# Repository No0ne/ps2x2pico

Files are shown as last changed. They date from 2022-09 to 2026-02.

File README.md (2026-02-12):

# ps2x2pico
USB keyboard/mouse to PS/2 interface converter using a Raspberry Pi Pico

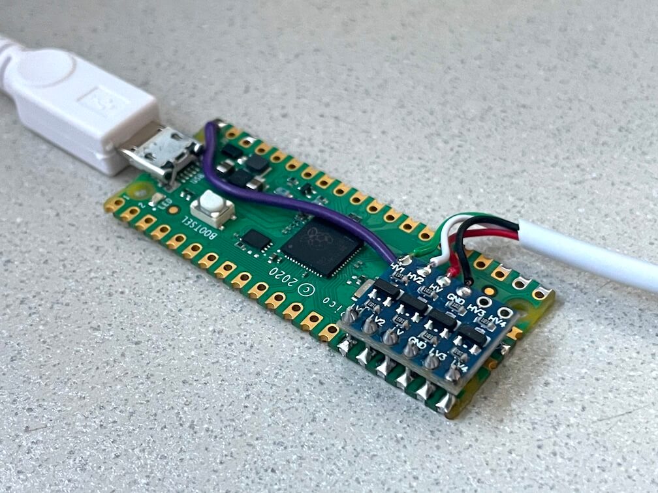
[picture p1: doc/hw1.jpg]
hw1
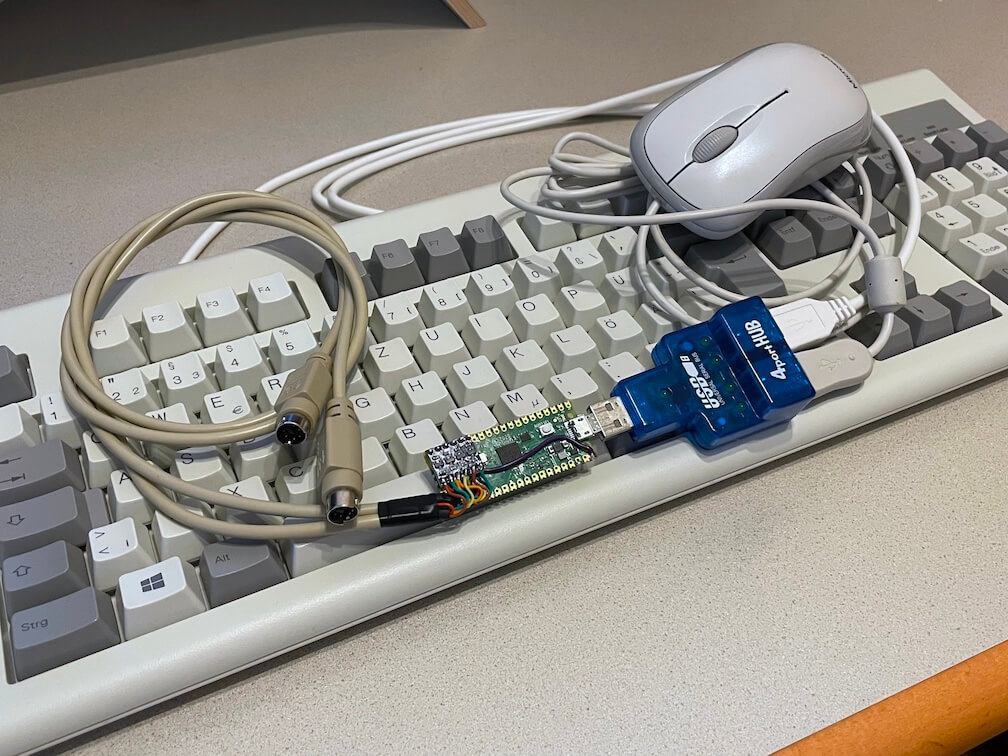
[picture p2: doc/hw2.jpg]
hw2
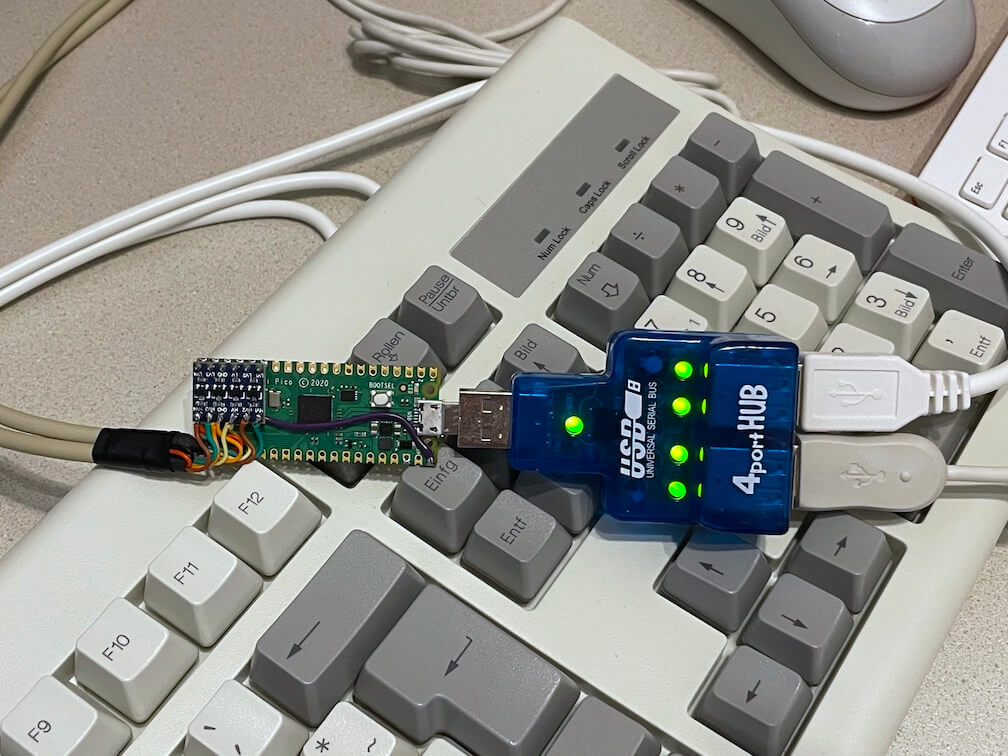
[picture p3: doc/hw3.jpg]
hw3
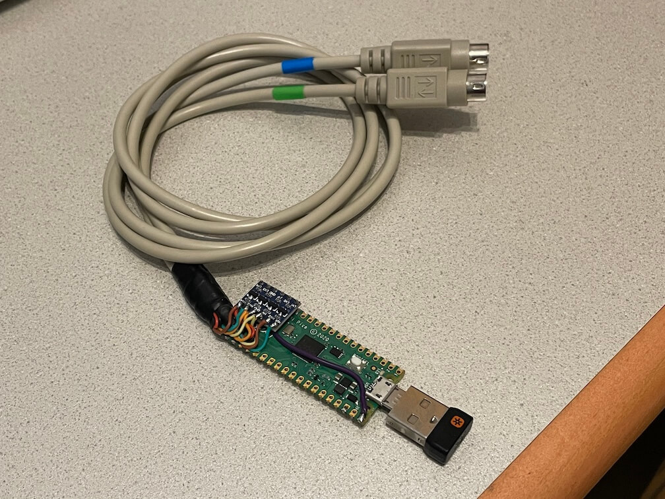
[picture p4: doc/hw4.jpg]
hw4
| | | | |
|-|-|-|-|

Keyboard only (incl. PC-XT) variant: https://github.com/No0ne/ps2pico  
There is also an alternative ps2pico firmware for the PC-XT and ps2x2pico hardware: [ps2pico-XT-alt.uf2](https://github.com/No0ne/ps2pico/releases/tag/2.2)

Additional excellent documentation by Ray: https://minuszerodegrees.net/keyboard/ps2x2pico.htm

[PicoMiteVGA](https://geoffg.net/picomitevga.html) variant: https://github.com/No0ne/hid2cdc

[PiKVM](https://pikvm.org) integration:
* https://docs.pikvm.org/pico_hid/
* https://docs.pikvm.org/pico_hid_bridge/

[ITX-Llama](https://www.vogons.org/viewtopic.php?t=93480) integration:
https://github.com/eivindbohler/itxllama

# Usage
* Download `ps2x2pico.uf2` from https://github.com/No0ne/ps2x2pico/releases
* Copy `ps2x2pico.uf2` to your Pi Pico by pressing BOOTSEL before pluggging in.
* 3.3V/5V conversion is done using a bi-directional level shifter: https://learn.sparkfun.com/tutorials/bi-directional-logic-level-converter-hookup-guide/
* Afterwards connect a USB keyboard and/or mouse using an OTG-adapter and optional USB hub.
* Also works with wireless keyboards and mice with a dedicated USB receiver.

⚠️ Please note that some older motherboards have non-resettable fuses rated
under 300mA.

**Check the power consumption of your keyboard/mouse/hub first before plugging
in!**

Level Shifter wiring diagram

PS/2 Pinout diagram

⚠️ Do not assume wire colors will match cables depicted in photos. Double-check
your pinout with a multimeter.

# PS/2 passthru
If you also want to use a real PS/2 keyboard and mouse together with your USB devices you can mount another level shifter on top of the pico. These two ports work as PS/2 inputs and are passed through to the PS/2 output ports.
* GPIO3 LV1 - keyboard data
* GPIO4 LV2 - keyboard clock
* GPIO5 LV - 3.3V pull-up
* GND - GND
* GPIO6 LV3 - mouse data
* GPIO7 LV4 - mouse clock

Don't forget to wire HV to 5V and your PS/2 sockets to power the connected PS/2 devices.

PS/2 passthru is especially useful with the PiKVM [Pico HID](https://docs.pikvm.org/pico_hid/) or [Pico HID Bridge](https://docs.pikvm.org/pico_hid_bridge/) as you can continue using your existing peripherals.  
⚠️ Please note that the [UF2 from PiKVM](https://github.com/pikvm/kvmd/releases) uses different GPIOs due to jumper pins:
* GPIO26 LV1 - keyboard data
* GPIO27 LV2 - keyboard clock
* GPIO16 LV3 - mouse data
* GPIO17 LV4 - mouse clock

Don't forget to wire LV to 3.3V and GND to GND separately as the level shifter does not fit directly on top of the pico. 

# Troubleshooting
You can hook up a USB serial adapter to **GPIO0** for additional debugging output. The serial settings are **115200** baud, **8** data bits and **no parity**. You can also use another Pico running the [pico-uart-bridge](https://github.com/Noltari/pico-uart-bridge) for this.

⚠️ If you have a **YD-RP2040** (see silkscreen on back of board if unsure) and
are not using a USB hub with its own power supply, you need to bridge two pads
of the diode pair near the USB-C port as seen here:

Fix for YD-RP2040

# Build

Install needed libraries and tools:

```sh
sudo apt install cmake gcc-arm-none-eabi build-essential pkg-config libusb-1.0-0-dev libusb-1.0-0
```

Get the Raspberry Pi Pico SDK version 1.5.1:

```sh
git clone https://github.com/raspberrypi/pico-sdk
export PICO_SDK_PATH=/path/to/pico-sdk
cd $PICO_SDK_PATH
git checkout 1.5.1
git submodule update --init
```

Update to the latest TinyUSB release 0.17.0:
```sh
cd $PICO_SDK_PATH/lib/tinyusb
git checkout 0.17.0
```

Generate the UF2 file:
```sh
cd /path/to/ps2x2pico
mkdir build
cd build
cmake ..
make
```

# Case

There are two case versions for this project, one for the hat variant in `freecad/` and one for the level shifter version in `openscad/`.

## Level shifter version

The case is snap fit and doesn't require any fasteners. You can print it as is using `ps2x2pico_case.stl` in your slicer but various customisation options are included in the underlying OpenSCAD model `ps2x2pico_case.scad` should you need them. This allows you to adjust tolerances or clearances of the height of the case and the various holes and support posts.

Note that when opening the case in OpenSCAD the [BOSL2](https://github.com/BelfrySCAD/BOSL2) library is required.

# Resources
* https://github.com/No0ne/ps2pico
* https://wiki.osdev.org/PS/2_Keyboard
* https://wiki.osdev.org/PS/2_Mouse
* https://wiki.osdev.org/Mouse_Input
* https://wiki.osdev.org/%228042%22_PS/2_Controller
* http://www-ug.eecg.toronto.edu/msl/nios_devices/datasheets/PS2%20Keyboard%20Protocol.htm
* http://www-ug.eecg.utoronto.ca/desl/nios_devices_SoC/datasheets/PS2%20Mouse%20Protocol.htm
* Archive.org links for the dead links in the pages above
  * [Main page PS/2 Keyboard Protocol](https://web.archive.org/web/20160414014033if_/http://www.computer-engineering.org/ps2keyboard/)
    * [Scan code set 1](https://web.archive.org/web/20160410193756if_/http://www.computer-engineering.org/ps2keyboard/scancodes1.html)
    * [Scan code set 2](https://web.archive.org/web/20160414030011if_/http://www.computer-engineering.org/ps2keyboard/scancodes2.html)
    * [Scan code set 3](https://web.archive.org/web/20160410184920if_/http://www.computer-engineering.org/ps2keyboard/scancodes3.html)
  * [Main page PS/2 Mouse Protocol](https://web.archive.org/web/20160414013310if_/http://www.computer-engineering.org/ps2mouse/)

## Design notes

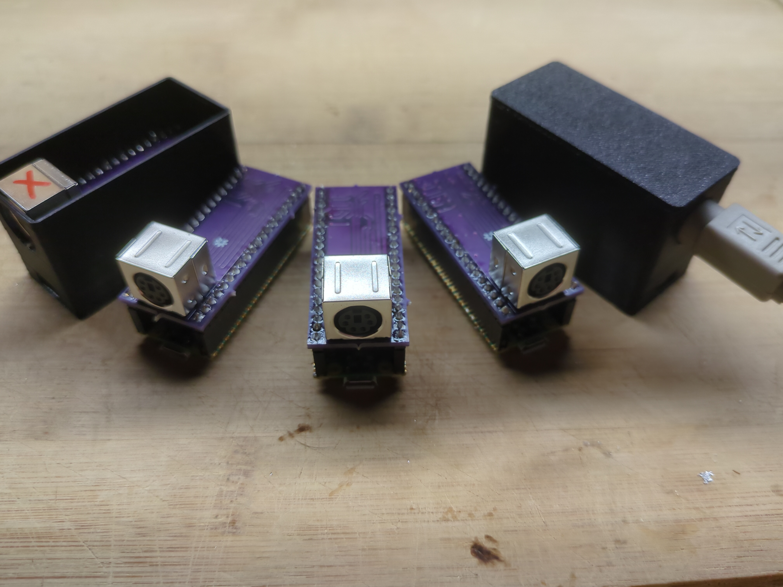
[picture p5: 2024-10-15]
doc/completed.jpg

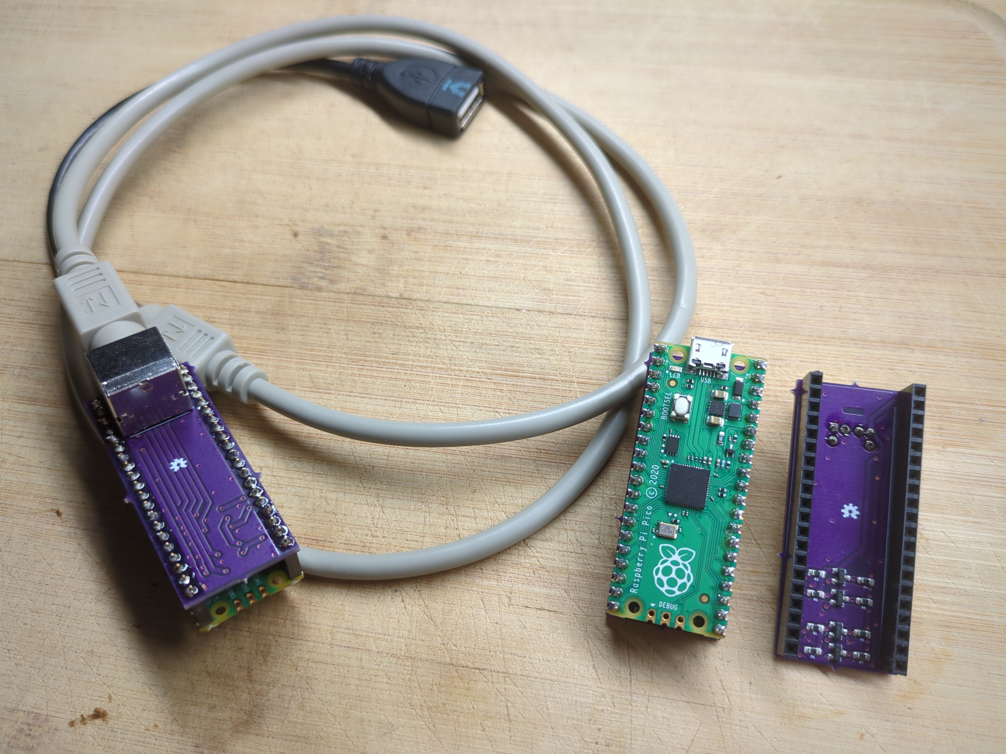
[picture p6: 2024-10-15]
doc/usb-to-ps2-prototypes.jpg

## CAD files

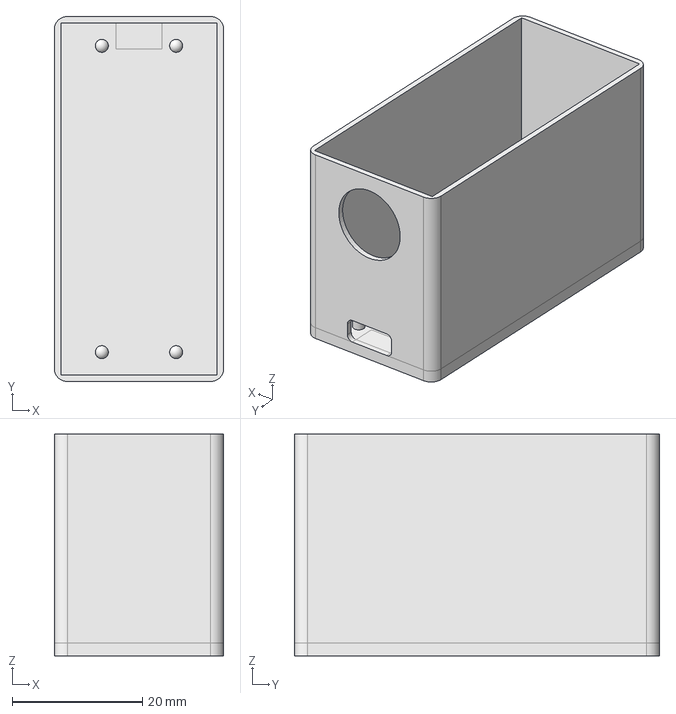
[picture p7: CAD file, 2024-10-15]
freecad/case.FCStd
26.0 x 56.0 x 34.0 mm

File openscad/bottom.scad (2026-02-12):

include <BOSL2/std.scad>
include <chamfered_section.scad>
include <usb_socket.scad>
include <cable_holes.scad>
include <pi_pico.scad>
include <rings.scad>
include <support_posts.scad>

module bottom(inner_ring_dimensions, rounding, wall_thickness, socket_cube, cable_holes_cube, usb_socket, front_scale_factor, ring_height, cable_diameter, hole_spacing, 
    chamfer_bottom_dimensions, chamfer_height, chamfer_top_dimensions, void_top, void_bottom, base_height, shift_distance, post_intervals, support_diameter, support_height, 
    retention_height, retention_diameter, total_post_height, posts_bounding_box, pico_height, support_adjustment, anchor = CENTER, spin = 0, orient = UP) {

  attachable(anchor, spin, orient, size=point3d(chamfer_bottom_dimensions, chamfer_height), size2=chamfer_top_dimensions) {
    // Chamfered section
    chamfered_section(chamfer_top_dimensions, chamfer_bottom_dimensions, wall_thickness, void_top, void_bottom, chamfer_height, base_height, rounding) {
      align(TOP) inner_ring(inner_ring_dimensions, rounding, wall_thickness, socket_cube, cable_holes_cube); // Inner ring
      align(TOP, FRONT) usb_socket(usb_socket, socket_cube, front_scale_factor, wall_thickness, ring_height, false); // Usb socket, bottom half
      align(TOP, BACK) cable_holes(cable_holes_cube, cable_diameter, hole_spacing); // Cable holes

      // Support posts
      align(BOTTOM, inside=true) {
        up(base_height) {
          fwd(shift_distance) support_posts(post_intervals, support_diameter, support_height, retention_height, total_post_height, posts_bounding_box, retention_diameter,
              support_adjustment, true) {
            // Pi Pico
            align(TOP) {
              hide_this() down(pico_height) pi_pico(pico_height);
            }
          }
        }
      }
    }

    children();
  }
}

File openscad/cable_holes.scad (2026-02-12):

include <BOSL2/std.scad>

module cable_holes(cable_holes_cube, cable_diameter, hole_spacing, anchor = CENTER, spin = 0, orient = UP) {
  module holes() {
    diff() {
      cube(cable_holes_cube, center=true);
      tag("remove") left((cable_diameter / 2) + (hole_spacing / 2)) cyl(h=cable_holes_cube.y + 0.02, d=cable_diameter, orient=BACK);
      tag("remove") right((cable_diameter / 2) + (hole_spacing / 2)) cyl(h=cable_holes_cube.y + 0.02, d=cable_diameter, orient=BACK);
    }
  }

  attachable(anchor, spin, orient, size=[cable_holes_cube.x, cable_holes_cube.y, cable_holes_cube.z / 2]) {
    up(cable_holes_cube.z / 4) bottom_half() holes();

    children();
  }
}

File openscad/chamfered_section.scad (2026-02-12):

include <BOSL2/std.scad>

module chamfered_section(chamfer_top_dimensions, bottom_dimensions, wall_thickness, void_top, void_bottom, chamfer_height, base_height, rounding, pinhole_diameter, pinhole=false,
    anchor = CENTER, spin = 0, orient = UP) {
  attachable(anchor, spin, orient, size=point3d(bottom_dimensions, chamfer_height), size2=chamfer_top_dimensions) {
    diff() {
      prismoid(size1=bottom_dimensions, size2=chamfer_top_dimensions, h=chamfer_height, rounding=rounding, center=true)
        // Inner void
        align(BOTTOM, inside=true) {
          up(base_height) {
            prismoid(size1=void_bottom, size2=void_top, h=chamfer_height - base_height + 0.01, rounding=rounding, center=true) {
              // BOOTSEL pinhole
              if(pinhole) {
                align(BOTTOM + FRONT) {
                  up(0.01) back(12.25 + (0.5 * pinhole_diameter)) left(3.75) cyl(h=base_height + 0.02, d=pinhole_diameter); 
                }
              }
            }
          }
        }
    }

    children();
  }
}

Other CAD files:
openscad/pi_pico.scad
openscad/ps2x2pico_case.scad
openscad/rings.scad
openscad/support_posts.scad
openscad/top.scad
openscad/usb_socket.scad

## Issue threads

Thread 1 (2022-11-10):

Mouse Issues

serisman, 2022-11-10:
First of all, awesome project!

It was super easy to get a Logitech wireless keyboard/mouse (K345/M275) combo up and running on an old DOS PC with only PS2 ports.

I haven't found any issues with the keyboard at all, but the mouse code seems buggy.

I am testing with both the CTMOUSE.EXE driver as well as Microsoft MOUSE.EXE driver.  With both drivers, by default, the mouse cursor jumps around pretty randomly and it seems like button presses are being toggled without actually pressing anything.  No amount of tweaking the driver's resolution seems to help things.  Eventually, I found that the /O switch on CTMOUSE (which enables wheel support) seems to work... about half the time.  Other times it just reports 'Error: device not found".

I think what is happening is that this code is always reporting 'Mouse with scroll wheel' and sending 4-byte 'Intellimouse' data packets, even when the computer hasn't asked for them (yet).  If I'm reading the documentation at [(https://wiki.osdev.org/PS/2_Mouse)](https://wiki.osdev.org/PS/2_Mouse) correctly, it seems like by default the mouse is supposed to report back type 0 'Standard PS/2 mouse' and send 3-byte data packets until a specific initialization sequence is requested to put the mouse into enhanced mode at which point it will report back type 3 'Mouse with scroll wheel' and send 4-byte data packets.

serisman, 2022-11-10:
I did some further testing, and my assumption was indeed true.  I made some code changes and now it works much better.  I'll clean it up and submit a pull request sometime tomorrow for you to review.

No0ne, 2022-11-10:
Hi, thanks for your feedback!
Yes you are right, the mouse support is still very sparse.

I've currently only tested it on Windows 2000 as there are still some issues left. I need to port the PS/2 protocol part to the Pico PIOs so that both channels can send/receive independently. At the moment it is just a port from [/No0ne/ps2pico] where CPU based bitbanging was enough since theres only the keyboard ps/2 channel. In my other repo [/No0ne/ps2x2pico-rs] I already tried PIO support with Rust, but there USB support is more of a problem.

I also found out that all my USB mice with the PixArt chip still do native PS/2 using the green passive adapter!
E.g. the official Raspberry Pi Mouse or the Microsoft Basic Optical Mouse

I hope I'll finish the PIO implementation this year.

serisman, 2022-11-11:
I'm using this with a Logitech wireless keyboard/mouse receiver, so those green passive adapters won't work for me.  :(  That's why I was excited to find your project to begin with.

I just submitted Pull Request #2 with some better mouse code for you to review.  It still isn't a 100% complete mouse driver, but does the main stuff better than before (i.e. switching between the different mouse types and honoring the corresponding data packet format).

I have tested this in MS DOS with the CTMOUSE.EXE and MS MOUSE.EXE drivers as well as with Windows 3.11, and all seems well.  I did run into a weird race condition when trying to run `ctmouse /o` where the 'key up' event of the ENTER key from running the command takes time away from the mouse initialization and causes weird issues.  If I just use `ctmouse` or put the command in a batch file with a pre-delay, everything works correctly.  I suppose what you mention about using PIO is probably the real solution that is needed.

No0ne, 2022-11-11:
Thanks for your PR!
Quick sidenote: I did compile the UF2s with Pico-SDK develop branch because of this https://github.com/raspberrypi/pico-sdk/issues/483
Will do a new release with your enhancements soon!

serisman, 2022-11-11:
Yeah, I had to do something similar.  I think I just updated the tinyusb git submodule to the latest.  Without doing that, only the keyboard was working.  Took a while to track that one down.  Finally realized I could get some debugging info by connecting a USB TTL serial to the UART!

serisman, 2022-12-05:
That looks pretty promising!  I'll have to check it out in more detail later.

I had one other thought for optimization, although I'm not sure how useful it would be once the PIO work is done.  Anyway, might be helpful to have all the serial logging controlled by a debug flag and produce two different binaries (one for run-time, one for debug).  The serial output is very useful for debugging, but it does steal some time from the PS/2 code.  During normal operation it seems kinda wasteful for all that serial processing to continue to happen.  It's like shouting into the void with no one listening.

No0ne, 2022-12-07:
Please try the new binary from the pio-testing branch: https://github.com/No0ne/ps2x2pico/raw/pio-testing/ps2x2pico.uf2
I've only tested it on Windows 2000 so far, but there still seams to be an issue if you drag the typematic sliders in the keyboard preference panel. The mouse starts jumping vertically. Also the PIO code is still messy right now.

serisman, 2022-12-16:
@No0ne - I finally had a chance to do some testing of your pio-testing branch, and everything seems to be working fine on my side.  I did some testing with both MS-DOS 6.22 as well as Windows 3.11 and didn't notice any issues.  Good job!

No0ne, 2022-12-17:
Cool! I still have issues on Windows 2000, especially when changing key repeat settings in the system control panel. I think I need to capture some data between real PS/2 devices and different PCs and mimic the timings as close as possible.

No0ne, 2022-12-18:
The PIO code is much more refined right now, but still not working 100% of the time.
Please try if this is still happening with the latest build [5f96329]:
> I did run into a weird race condition when trying to run `ctmouse /o` where the 'key up' event of the ENTER key from running the command takes time away from the mouse initialization and causes weird issues.

Thanks!

serisman, 2022-12-23:
> The PIO code is much more refined right now, but still not working 100% of the time. Please try if this is still happening with the latest build [[5f96329](https://github.com/No0ne/ps2x2pico/commit/5f96329b8873e4b1af6377f1dd1dfc8af90bc5fa)]:
>
> > I did run into a weird race condition when trying to run `ctmouse /o` where the 'key up' event of the ENTER key from running the command takes time away from the mouse initialization and causes weird issues.

Sorry, but with the current version the mouse isn't working at all.  It works again if I rollback to the Dec 7th version as long as I have ctmouse in the autoexec.bat, but not if I just type it on the command line.

nanoant, 2023-08-20:
@No0ne @serisman Can you guys share Dec 7th version? (the link above is broken) The latest beta 0.6 does not work at all on my Toshiba 430CDT using my build described at #16. I see lot of communications in oscilloscope, but in the end laptop is not taking any external mouse events.

No0ne, 2023-08-20:
I'm currently rewriting the whole PIO code as part of integrating to the PiKVM pico hid project. I hope this will fix all mouse related issues, please give me some to finish.

No0ne, 2023-08-27:
@serisman if you still have the board around you could test the new pre-release: https://github.com/No0ne/ps2x2pico/releases/download/beta-0.7/ps2x2pico.uf2
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
nvllsvm, 2024-03-16:
V1.0 alpha works well with my G305 @ 500hz, though I needed to use PS2Rate to change the rate in Windows 98. The default was very choppy compared to using the same mouse with the [Minicom PS2 to USB adapter](https://www.amazon.com/gp/product/B00404YD8W/ref=ppx_yo_dt_b_search_asin_title?ie=UTF8&psc=1).

There also might be some small latency issues, though I'll need to test more.

No0ne, 2024-03-18:
Just checked and yes, Win98 default sets the rate to 0x28 = 40hz which means 25ms between transmits. I currently apply the sample rate requested by the host but if you want we could also hardcode it. Please explain if you have more details about stuttering, thanks!

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

seritools, 2024-03-24:
Just tested again with 1.0, works flawlessly over here. 🎉

And wow, PS2Rate makes a huge difference, TIL Win9x sets it to such a low value. Maybe having a second FW version or a HW switch through another GPIO for forcing a sample rate might make sense?

nvllsvm, 2024-03-24:
I've been testing a modification which forces a constant sample rate without any issues.
https://github.com/nvllsvm/ps2x2pico/commit/f867858986a37cafbccab6e7d057983de4874b4e

Both 100hz and 200hz are working well enough for me to comfortably replace the Minicom adapter I was using. Playing Unreal on Windows 98 feels fantastic and responsive.

[ps2x2pico_mouse_100hz.uf2.tar.gz](https://github.com/No0ne/ps2x2pico/files/14736769/ps2x2pico_mouse_100hz.uf2.tar.gz)
[ps2x2pico_mouse_200hz.uf2.tar.gz](https://github.com/No0ne/ps2x2pico/files/14736770/ps2x2pico_mouse_200hz.uf2.tar.gz)

No0ne, 2024-03-28:
Just checked that 200hz with mouse wheel enabled doesn't work without overclocking the ps/2 port.
The fourth byte is around the 5ms mark which the next first byte should be.
With a 2x overclock the transmission is still a bit choppy but with over 20kHz clock this exeeds the proposed max 16kHz.

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

No0ne, 2024-03-28:
Correction: it does start to work above around 14.5kHz so I could release a 200Hz version with a higher clock.

No0ne, 2024-03-28:
5628f15 is now optimized, 200Hz mouse movement should work now.
PS/2 clock is at 15.625kHz and theres a little bit more than one byte of time space between mouse packets 🥳

nvllsvm, 2024-03-28:
> [5628f15](https://github.com/No0ne/ps2x2pico/commit/5628f15e4999bbc766244dda96cc425ffdc37cec) is now optimized, 200Hz mouse movement should work now. PS/2 clock is at 15.625kHz and theres a little bit more than one byte of time space between mouse packets 🥳

I wasn't having any issues with the wheel previously, but I've confirmed this change works on my end (ABit AV8 motherboard).

ssokolow, 2024-03-28:
Once the pack of level shifters I've ordered arrives in about a month, I should be able to test on an HP t5530 thin client that's been repurposed as a Windows 98 SE machine, a cheap Chinese USB/VGA KVM switch that doubles as a hub, a Rosewill RK-9000I mechanical keyboard,  and a Logitech G203 Prodigy mouse.

(The thin client has USB but the aftermarket USB 2.0 drivers for Windows 98 SE crash with Fatal Error 0E if you unplug the USB keyboard or mouse while running and I want something I can KVM without having to find and pay for a KVM switch which emulates permanently connected screen, keyboard, and mouse to minimize switching latencies.)

No0ne, 2024-03-29:
> I wasn't having any issues with the wheel previously, but I've confirmed this change works on my end (ABit AV8 motherboard).

Thats true but it wasn't 200Hz either as it missed every other send slot. On the first screenshot https://github.com/No0ne/ps2x2pico/issues/1#issuecomment-2025216369 the marker 2 is on 5ms where the next mouse packet should have started. Raising the clock made each bit shorter to make more room.

nanoant, 2024-03-30:
I was testing [ps2x2pico_mouse_200hz.uf2.tar.gz](https://github.com/No0ne/ps2x2pico/files/14736770/ps2x2pico_mouse_200hz.uf2.tar.gz) attached previously by @nvllsvm on my 430CDT and it was almost perfect. It glitched once for a short while but recovered itself.

Does it correspond to [5628f15](https://github.com/No0ne/ps2x2pico/commit/5628f15e4999bbc766244dda96cc425ffdc37cec) with optimized 200Hz? Or shall I build the latest commit myself?

nvllsvm, 2024-03-30:
@nanoant It was for an older commit. Here's a build for https://github.com/No0ne/ps2x2pico/commit/5628f15e4999bbc766244dda96cc425ffdc37cec

[ps2x2pico_5628f15_200hz.uf2.tar.gz](https://github.com/No0ne/ps2x2pico/files/14813101/ps2x2pico_5628f15_200hz.uf2.tar.gz)

No0ne, 2024-04-19:
Here is the 1.0 release: https://github.com/No0ne/ps2x2pico/releases/tag/1.0

Thanks everyone in this thread for contributing.
Please open a new issue if you have further mouse releated issues/updates.

Closed 2024-04-19.

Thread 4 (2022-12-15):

Q. Should I connect both keyboard and mouse?

zmotme, 2022-12-15:
I am very interested on your project. But I have little knowledge about electric and embedded.

I know you already informed keyboard only project, but I found it is easier to get 4ch logic level shifter, I soledered rp2040 clone - may be yd-rp2040, and not wired mouse.

It did not worked. So I’ve ordered original rp2040 board and trying to make one.

When I connect rp2040 to ps/2, board led turns on even though PC was turned off.

I have no idea about it.

Should I connect both keyboard and mouse connect?

Or my PC send power when turned off makes problem?

I hope original rp2040 and keyboard mouse connection can solve this!

No0ne, 2022-12-15:
Hi! Yes it is perfectly ok if you just connect the ps/2 keyboard port. It also should work with any other rp2040 board as long as the GPIO numbers match up. If not, you'll need to edit the pin definitions at the beginning of the source file and compile the software your self. Also check that the clock and data lines are connected correctly, they can not be swapped.

```
#define KBCLK 11
#define KBDAT 12
#define LVPWR 13
#define MSCLK 14
#define MSDAT 15
```

Currently I'm switching the software over to send ps/2 fames via the rp2040 PIOs on the pio-testing branch which also should make the mouse part more stable which it isn't at the moment (keyboard should be fine).

Regarding power when the PC is off: yes, this is a feature of most motherboards!
There should be a jumper on the motherboard which enables/disables PS/2 power when the PC is off.
And in the BIOS you can configure how to turn on the PC via e.g. space bar, enter or a dedicated power button on the keyboard if it has one. This should also work with ps2x2pico, but I haven't testet that yet.

Closed 2023-01-07.

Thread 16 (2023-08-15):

Data and clock pins reversed according to oscilloscope measurement?

nanoant, 2023-08-15:
First of all I want to share news that I managed to build working unit with HW-221 TXS0108E level converter that I had lying around:
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
Notable differences:
1. GPIO13 is connected to OE of TXS0108E, instead of powering the unit. TXS0108E is powered from 3.3V and 5V pins.
2. Only 4 of 8 are used and shifter is on the back of Rpi Pico, but HW-221 board is extremely cheap so IMHO can be better bang for buck for this project. And I have quite a stock of these boards.
3. Looks there's a short between GND and A3, but actually they don't touch, and there's additional transparent isolation.
4. I did not solder PS/2 plugs, instead use Dupont, since I want also to talk with boards/FPGA that have PS/2 pins but no proper sockets.

Now the problem. According to my oscilloscope I see keyboard clock on GPIO11 and data on GPIO12, which is opposite from what is written in the documentation. I checked both level shifter and Pi pins. This looks like some trivial problem but I have honestly no clue why this is happening. Any thoughts?
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

No0ne, 2023-08-15:
Hi, nice work/photos!
I'm currently in the process of swapping pins, see https://github.com/No0ne/ps2x2pico/releases/tag/beta-0.6
The PIO code which uses data before clock isn't finished yet.
The old CPU bitbang code did use clock before data on the GPIOs.
Hope this clarifies your issue!

Closed 2023-08-16.

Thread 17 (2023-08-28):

Freezing on KVM

yarodin, 2023-08-28:
I have KVM with 4 computers attached, ps2pico plugged to PC4 KVM USB port.
ps/2 ports on ZX Evolution <-> ps2pico <-> PC4 USB port on KVM / Common USB port <->  USB  Logitech unifying receiver -> Logitech Mouse & Keyboard

If I switching on ZX Evolution with KVM setted to PC4 - all works perfectly untlil I have switched to PC1/2/3 computer - after several second ps2pico stop acting. Same problem if I switching on ZX Evo with KVM setted to PC1/2/3.

No0ne, 2023-08-28:
Which hardware do you use? ps2pico or ps2x2pico?
Which firmware version did you download?

yarodin, 2023-08-28:
ps2x2pico
beta-0.5

No0ne, 2023-08-28:
please try out the new pre-releas beta-0.7
(remember to swap each data/clock pin pair on the 5V side)

yarodin, 2023-08-29:
I updated firmware to beta-0.7.

"If I switching on ZX Evolution with KVM setted to PC4 - all works perfectly untlil I have switched to PC1/2/3 computer - after several second ps2pico stop acting" - this case fixed, thanks a lot.

"Same problem if I switching on ZX Evo with KVM setted to PC1/2/3." - this is not fixed.

No0ne, 2023-08-29:
Did you connect mouse and keyboard to the KVM or keyboard only?

yarodin, 2023-08-29:
I have one USB Logitech unifying receiver plugged to KVM and mouse and keyboard connected through it.

No0ne, 2023-08-29:
Ok, and both stop working? or only the mouse?

yarodin, 2023-08-29:
if I switching on ZX Evo with KVM setted to PC1/2/3 and then setting KVM to PC4 mouse and keyboard not working on PC4, but still normaly working on PC1/2/3.

Seems, ps2x2pico isn't working if mouse and keyboard is not plugged to USB (or switched off by KVM) when it power on.

No0ne, 2023-08-29:
Ah yes, if theres nothing connected to usb it reports an error on the ps/2 side! I think i could add a jumper setting to disable that an always report OK on ps/2.

No0ne, 2023-09-16:
[ps2x2pico.zip](https://github.com/No0ne/ps2x2pico/files/12641676/ps2x2pico.zip)
Please retry with this binary, its currently hardcoded to always answer OK.

yarodin, 2023-09-17:
This version is working in all cases with KVM. You can close issue. Thanks.

No0ne, 2023-09-17:
Thank you for the feedback!

Closed 2023-09-17.

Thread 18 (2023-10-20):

like use this on agon light 2

tenij000, 2023-10-20:
like use this on agon light 2

it got a usb connector female but needs a ps2 keyboard

No0ne, 2023-10-23:
Yes this should work. Connect a USB cable as shown here: https://raw.githubusercontent.com/No0ne/ps2x2pico/main/hw1.jpg
But you have to swap green and white with software beta-0.7 and above.

Closed 2023-10-23.

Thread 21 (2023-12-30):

Keyboard not reconnecting after power cycle

peek82, 2023-12-30:
I'm using a ps2x2pico w/ a Picomite (keyboard only) and have wired up two versions, one using the level shifter board as prescribed, and one using direct wiring from pico to pico with 4k7 'pullups' going to GP13 of the ps2x2pico. Both versions work well until a power cycle, after which I need to reset the ps2x2pico by grounding the run pin before it will reconnect to the keyboard again. As a workaround, I am toggling the run pin on boot with an extra GPIO on the picomite. Love being able to use a USB keyboard for input, much thanks!

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

No0ne, 2024-01-04:
I'm currently doing another project for the picomite: https://github.com/No0ne/hid2cdc
It is hooked up like this: https://www.thebackshed.com/forum/ViewTopic.php?TID=16545&P=1
But its not finished yet, F-keys are not working.

For debugging the powercycle bug, an you hook up a serial console to GPIO 0 and post the output?
It is sending at 115200n8

peek82, 2024-01-09:
Thank you for the reply but when I moved from the breadboard to soldered connections the problem went away, so I'm chalking it up to a buggered up breadboard / jumper wires. It's functioning perfectly now, I really appreciate your work on this & the hid2cdc project. My current use case requires the ps2 version but I'll definitely be looking at using hid2cdc in the future.

No0ne, 2024-01-09:
Cool, thanks!

Closed 2024-01-09.

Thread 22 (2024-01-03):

Does not work with YD RP2040

Chandler-Kluser, 2024-01-03:
This is an interesting issue (in my opinion)...

First of all, thanks for sharing this great project!!! It worked as expected with my original Raspberry Pi Pico Board using a micro USB OTG adapter to my USB keyboard...

Then I used this [YD-RP2040](https://github.com/initdc/YD-RP2040/blob/master/YD-2040-2022-V1.1-SCH.pdf) board:

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

with an USB Type C OTG adapter, but it does not work... the board is completely pin compatible with the Raspberry Pi Pico...

Do you have any clue? Thanks in advance :smile:

No0ne, 2024-01-04:
Can you hook up a serial console to GPIO 0 and post the output?

Chandler-Kluser, 2024-01-05:
it is not outputing anything, when I turned on the first time it showed:

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

Are you sure the configuration is 115200 8-N-1?

No0ne, 2024-01-08:
🤔 hm you should get at least this string: "ps2x2pico-0.8 DEBUG=false"

Chandler-Kluser, 2024-01-08:
I am so sorry :sweat_smile:

I had trouble with the UART interface while using another USB device, which were in conflict...

About the YD-RP2040, it actually worked with the built in .uf2 file in releases :smile:

Thanks and I am sorry for bothering!!

Chandler-Kluser, 2024-01-09:
I have actually find out that it can be these QSPI flashes, some of these boards have lower memory size.

Another thing could be that this YD board (right side on the picture) have RGB light, I don't know if it is using any GPIO for ps2x2pico...

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

I took this left board from WeAct Studio and it worked flawlessly as well as the Raspberry Pi Pico (Raspberry Pi Foundation Official Board).

Thanks one more time for this great project!!

No0ne, 2024-04-19:
Seems to the that Pin 20 aka Vout aka VBUS is connected after the diode on the YD-RP2040, see: https://github.com/No0ne/ps2x2pico/issues/33#issuecomment-2066438989

Closed 2024-01-08.

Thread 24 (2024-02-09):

[feature request] PS2 input repeating

Gouster4, 2024-02-09:
Hello. I would like to use this project on my KVM which is almost older than me and has only PS2 port. But i would also like to keep my RKM working, which has ps2 output.

Can you please make optional PS2 input, so it can repeat PS2 input and also convert USB to PS2?  This way i can connect both USB keyboard and PS2 keyboard to raspberry, and use both inputs. Maybe it will cause issues when used simultaneously, but otherwise it should be ok. Thank you.

No0ne, 2024-02-10:
Yes! In fact I'm already working on it because of this related issue: https://github.com/pikvm/pikvm/issues/476

I'm experimenting with an 8-channel level shifter, but I think I got the wrong part wich isn't suitable for open-drain circuits. But I can always use two 4-channel ones. I'll keep you updated if I made progress!

Gouster4, 2024-02-10:
Thats awesome. Thank you.

Now bit unrelatwd question, but dont want to open new issue report.
I would also like to know if this project can run on rp2040 zero with 2M flash. Thank you, and sorry for unrelaedd question.

No0ne, 2024-02-10:
I think this should work with any rp2040 board.

Gouster4, 2024-02-12:
Awesome. I would rather re-route cables from controller to level converter to keep gpio pins same if possible. I would like to prepare my hardware for PS2 passtrought, do you have already plans which gpio pins you will use for ps2 input once you implement ps2 passtrought? Are there also some specific requirements for pin capabilities for data or clock? Or basically any gpio pins can be used?

Thank you.

Gouster4, 2024-02-13:
Can you comfortably use pins between gpio0 and gpio10? Because those are present and easy accessable also on zero version. Basically 0-15&26-29 are easy accesable, 17-25 are still accessable but requires precise soldering on small solder pads with small gaps between, but still good enought. GPIO 16 is missing. I think, if usable, then requires microscopic soldering to chip/soc itself.

If it wouldnt be possible to confortably use gpio0-15 pins, there is still way to chagne gpio and compile for myself. But its easier to be up-to-date when using releases.

gpio 11-15 used as ps2 output are easy accessable on zero version without any issues. So thats perfect. Luck for users with zero version, because i cannot imagine changing existing pins in this project when lot of people have already soldered those exact pins to support releases instead of compiling themself.

Just let me know how did you decided. Its not a big deal for me to change gpio and compile, but if it would be possible to use gpio0-10 and still keep it good looking on non-zero type of board, it would be way easier for all users with zero version.

Thank you

No0ne, 2024-02-13:
Sure, I corrected this for PS/2 input:
```
                   _________________
                  |                 |
Pico GPIO3 ______| LV1         HV1 |______ PS/2 keyboard data
Pico GPIO4 ______| LV2         HV2 |______ PS/2 keyboard clock
Pico GPIO5 ______| LV          HV  |______ PS/2 5V + Pico VBUS
Pico    GND ______| GND         GND |______ PS/2 GND
Pico GPIO6 ______| LV3         HV3 |______ PS/2 mouse data
Pico GPIO7 ______| LV4         HV4 |______ PS/2 mouse clock
                  |_________________|
```

No0ne, 2024-02-16:
I've cobbled together the first prototype: only keyboard is working at the moment and also only one data direction, meaning the leds on the keyboard don't get set.

Please try this: https://github.com/No0ne/ps2x2pico/raw/24-ps2-input/ps2x2pico.uf2

I also added two 3.3k pull-up resistors from HV1 to HV and HV2 to HV as the built-in 10k from the levelshifter might be too weak for your keyboard, you'll have to try it out.

Gouster4, 2024-02-17:
Thank you. Im still waiting for levelshifters. But maybe i can prototype my own temporary level shifter from pocally available components to test it.

No0ne, 2024-02-17:
You can try to run your keyboard on 3.3 Volts, maybe it works. Then you don't need a level shifter, only two pull-up resistors.

No0ne, 2024-04-07:
Did you have time to try it out?

Gouster4, 2024-04-07:
> Did you have time to try it out?

Sorry. I went to work trip, and im out of my tech for a while. Only access i have is remote services running at my server.

But in about 2 weeks i will be at home.
And i already recived level shofters, which my wife picked up. So, once i get home im ready to test it.

Gouster4, 2024-04-28:
Finally got home, and put that together.
Keyboard is working exaclty like you described.
Do you plan to add mouse support, and keyboard leds support.

Thank you

No0ne, 2024-04-28:
Thats cool to hear, yes I'll add mouse passthru support as I also need it for the PiKVM integration.

For the other issue, please post a diagram which devices are connected how.

Gouster4, 2024-04-28:
> lease post a diagram which devices are connected how.

Awesome. My plan is also to use PiKVM, but old X86 unofficial release of PiKVM as VM on my main server, with USB-Uart adapter (keyboard+mouse from PiKVM VM to KVM switch) adapter and Video Grabber passed trought to VM.

Currently, im using Belkin´s Matrix2 KVM, HP RKM and bunch of Servers.
On that HP rkm, i replaced ball mouse to some random touchpad from some broken laptop.

HP RKM(with replaced ps2 touchpad) -> Belkin´s Matrix2 KVM -> HP DL380p Server.

Before touchpad replacement, it was working.
Now im using ps2 mouse instead, and i have connected touchpad with PS2->USB converter directly to Server, as KVM doesnt like it.

For future, i would like to integrate ps2x2pico into KVM case like cutting wires on original ps2 connector of keyboard/mouse input, and connecting it trought ps2x2pico, and add 3 usb ports (2 TypeA connected to USB hub which connects to ps2x2pico, and 3rd typeC (for PiKVMx86) which would be connected to USB hub, where video grabber card and usb-uard bridge would be connected.)

No0ne, 2024-04-29:
Ah yes now I understand. It will most certainly fix the touchpad problem as the PS2 input and output are isolated as in no bytes travel directly from in out. The PS2 input rather controls the virtual mouse created on the PS2 output same as the USB input events do.

Gouster4, 2024-04-29:
> It will most certainly fix the touchpad problem as the PS2 input and output are isolated, as in no bytes travel directly from in to out. The PS2 input rather controls the virtual mouse created on the PS2 output, same as the USB input events do.

Thats awesome. Thank you. Looking forward for mouse support. 👍

No0ne, 2024-06-14:
Sorry, took me a bit longer to find time for this 😯
Try this, now keyboard and mouse should work:
[ps2input.zip](https://github.com/user-attachments/files/15841002/ps2input.zip)

Gouster4, 2024-06-14:
> Sorry, took me a bit longer to find time for this 😯 Try this, now keyboard and mouse should work: [ps2input.zip](https://github.com/user-attachments/files/15841002/ps2input.zip)

Thank you so much. I'm on work trip again, but I will be at home in about two weeks, so will definitely test this out. Looking forward to test it.

Is this with PiKVM support on RX&TX pins included or without?

No0ne, 2024-06-14:
I currently have a pull request open for this: https://github.com/pikvm/kvmd/pull/171
Yes I tested this with the pico hid bridge over usb and it should also work over spi and serial.

No0ne, 2024-06-14:
But the pinout is different (uses 26+27 and 16+27) so for rp2040 zero we'll have to compile a custom pico hid bridge.

Gouster4, 2024-06-14:
> I currently have a pull request open for this: [pikvm/kvmd#171](https://github.com/pikvm/kvmd/pull/171) Yes I tested this with the pico hid bridge over usb and it should also work over spi and serial.

Nice. I will then make a fork, try to merge it, and keep current pin Configuration and build.

Gouster4, 2024-07-14:
https://github.com/No0ne/kvmd/commit/6c23bef9987d79c502e03830f7f64fa05967ca85

This is my attemp to get it working with same pins used as i tested here before.

No0ne, 2024-07-14:
Looks good, but you also need to disable and hardcode the jumper configurations since they share the same GPIOs like this:
```
diff --git a/hid/pico/src/ph_outputs.c b/hid/pico/src/ph_outputs.c
index 4ec40de5..472635a6 100644
--- a/hid/pico/src/ph_outputs.c
+++ b/hid/pico/src/ph_outputs.c
@@ -53,29 +53,29 @@ static int _read_outputs(void);

 void ph_outputs_init(void) {
 #	define INIT_SWITCH(x_pin) { gpio_init(x_pin); gpio_set_dir(x_pin, GPIO_IN); gpio_pull_up(x_pin); }
-	INIT_SWITCH(_PS2_ENABLED_PIN);
-	INIT_SWITCH(_PS2_SET_KBD_PIN);
-	INIT_SWITCH(_PS2_SET_MOUSE_PIN);
+	//INIT_SWITCH(_PS2_ENABLED_PIN);
+	//INIT_SWITCH(_PS2_SET_KBD_PIN);
+	//INIT_SWITCH(_PS2_SET_MOUSE_PIN);

-	INIT_SWITCH(_BRIDGE_MODE_PIN);
+	//INIT_SWITCH(_BRIDGE_MODE_PIN);

-	INIT_SWITCH(_USB_DISABLED_PIN);
-	INIT_SWITCH(_USB_ENABLE_W98_PIN);
-	INIT_SWITCH(_USB_SET_MOUSE_REL_PIN);
-	INIT_SWITCH(_USB_SET_MOUSE_W98_PIN);
+	//INIT_SWITCH(_USB_DISABLED_PIN);
+	//INIT_SWITCH(_USB_ENABLE_W98_PIN);
+	//INIT_SWITCH(_USB_SET_MOUSE_REL_PIN);
+	//INIT_SWITCH(_USB_SET_MOUSE_W98_PIN);
 #	undef INIT_SWITCH
 	sleep_ms(10); // Нужен небольшой слип для активации pull-up
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
No0ne, 2024-07-14:
I think you missed GPIO 7.

Gouster4, 2024-07-14:
Thanx. that makes perfectly sense. Now i leaved w98 mouse mode pins active, as i have those pins accessable, and it should break functionality i guess.
https://github.com/No0ne/kvmd/commit/c974a6a6189cbd97f6ea086bd5aa3bc7d2ff66e3

#define _MOUSE_IN_DATA_PIN 6
gpio6 is on pin number 7 i guess.

#define _USB_ENABLE_W98_PIN 7
should be gpio 7, so pin number 8, right?

Then it shouldnt be conflicting.

Gouster4, 2024-07-14:
does this also support usb input (USB->PS/2) like ps2x2pico?

No0ne, 2024-07-14:
8 and 9 are also used for _USB_SET_MOUSE_REL_PIN and _USB_SET_MOUSE_W98_PIN.

No, direct USB Input is not supported by the Pico HID, only via a PiKVM connection.

Gouster4, 2024-07-14:
> put is not supported by the Pico HID, only via a PiKVM connection.
So, ideally i should daisy-chain two raspberries pico, to get both USB and PiKVM input?
Or is there any other option?

No0ne, 2024-07-14:
Yes this should work. But I thought you had PS/2 keyboard and a touchpad in the first place?

Theres also the software route of enabling USB input on the Pico HID, but the hardware solution is definitly easier for now.

Gouster4, 2024-07-14:
> Yes this should work. But I thought you had PS/2 keyboard and a touchpad in the first place?
>
> Theres also the software route of enabling USB input on the Pico HID, but the hardware solution is definitly easier for now.

Yes, I have PS2 input from RKM, but I would like this KVM to accept also USB input, as it supports also USB output. Not sure what I would connect there in future.

But PS2 input is what I'm currently using, and would use for long time.

Gouster4, 2024-07-14:
Or USB is used to emulate mouse for host?
If so, then those:
+	//INIT_SWITCH(_USB_ENABLE_W98_PIN);
+	//INIT_SWITCH(_USB_SET_MOUSE_REL_PIN);
+	//INIT_SWITCH(_USB_SET_MOUSE_W98_PIN);
are used to set mouse mode for USB mouse emulation?

No0ne, 2024-07-15:
Correct, the boolean ph_g_is_bridge globally enables/disables USB emulation: https://docs.pikvm.org/pico_hid_bridge/

In the bridge configuration USB emulation is disables as its used to connect to the PiKVM.

No0ne, 2024-07-15:
I think the latency will not be noticeable.

Gouster4, 2024-07-15:
Can you please include kvmd/hid compatible input on uart in ps2x2pico? Or it would be too complex to do? No matter if it would be New "The Pico HID Bridge" or old implementation "The Pico HID" used for PiKVM V1.

No0ne, 2024-07-15:
Huh, no, I think thats out of the scope of that project and too complex.

No0ne, 2024-07-15:
Is the PS/2 touchpad routed through the input now working?

No0ne, 2024-11-15:
documented: https://github.com/No0ne/ps2x2pico?tab=readme-ov-file#ps2-passthru

Closed 2024-11-15.

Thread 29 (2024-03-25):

Mouse issues when using PS/2 to USB adaper

naplesap, 2024-03-25:
First of all, love this project. I've used it numerous times on PiKVM v2 but now I'm running into a unique issue. I have a device that has independent USB mouse and keyboard inputs. I used the Pico HID to convert the HID to PS/2, then two independent PS/2 > USB adapters to convert back to USB. Is there an easy way to tweak the code to allow the Pico to just isolate Keyboard from Mouse and output to two separate USB-A? Forgive my lack of coding knowledge.

My problem when using Pico Bridge on PiKVM v4+ is when converting the PS/2 mouse back to USB the screen scrolls when I move the mouse up and down as if I am holding down a scroll wheel or mouse button.

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

No0ne, 2024-03-25:
Hi, thats an interessting usecase! I think this should be possible using this project: https://github.com/sekigon-gonnoc/Pico-PIO-USB

You only would need a Pico, four 22 ohm resistors and two USB-A plugs. Do you have this on hand for testing?

Which PS/2 to USB adapters are you using? Maybe I could fix the mouse wheel issue.

naplesap, 2024-03-25:
I only currently have 4.7k ohm and 390 ohm resistors on hand, however I could easily order 22 ohm. I've tried both of the following PS/2 > USB adaptors with the same result:

https://www.amazon.com/gp/product/B00IACID2C/ref=ppx_yo_dt_b_search_asin_title?ie=UTF8&psc=1
https://www.amazon.com/gp/product/B00028OP2Y/ref=ppx_yo_dt_b_search_asin_title?ie=UTF8&th=1

naplesap, 2024-03-25:
I have ordered 22 ohm resistors that should be here in about 12 hours. I appreciate your help.

No0ne, 2024-03-25:
And the mouse wheel issue is exactly the same with both PS/2 adapters?

naplesap, 2024-03-25:
> And the mouse wheel issue is exactly the same with both PS/2 adapters?

Yes, the issue is exactly the same.

No0ne, 2024-03-25:
I ordered the startech one do I can reproduce/fix that.

naplesap, 2024-03-25:
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
I'm going to test this in a few hours. Do you happen to know if there is a video or instruction manual for the Pico-PIO-USB?

No0ne, 2024-03-25:
This is mainly a library and not a finished project. You could take a look in the examples folder I guess. I'll be able to try a pikvm integration after the easter holidays.

No0ne, 2024-03-26:
Got the Startech adapter today, tested it and it works fine. 😲
Maybe there was a fix since the last release, I'll build you a custom pikvm version with the 1.0 pre-release.

naplesap, 2024-03-27:
> Got the Startech adapter today, tested it and it works fine. 😲 Maybe there was a fix since the last release, I'll build you a custom pikvm version with the 1.0 pre-release.

That is far too kind of you. I really appreciate that. In the meantime I'm going to try to tinker with the Pico PIO USB and see if I can get that to work. Thanks again!

No0ne, 2024-03-27:
I asked if it is possible to generate two devices via the PIOs as I saw no obvious way to do so: https://github.com/sekigon-gonnoc/Pico-PIO-USB/issues/114

naplesap, 2024-03-28:
Testing it now and the issue seems to be the same. If i move the mouse up or down slowly the cursor barely moves but the page in the background seems to scroll insanely fast.

No0ne, 2024-03-28:
Did you also update pikvm it self via `[root@pi4kvm ~]# pikvm-update` ?
Which browser/OS are you using on the host system?

naplesap, 2024-03-28:
> Did you also update pikvm it self via `[root@pi4kvm ~]# pikvm-update` ? Which browser/OS are you using on the host system?

I just updated to the latest pikvm version. I'm using Win11 and Chrome Version 123.0.6312.59 (Official Build) (64-bit)

No0ne, 2024-03-28:
[hid-no-wheel.zip](https://github.com/No0ne/ps2x2pico/files/14790638/hid-no-wheel.zip)
Please try this, it forces a two button mouse without wheel.

naplesap, 2024-03-28:
> [hid-no-wheel.zip](https://github.com/No0ne/ps2x2pico/files/14790638/hid-no-wheel.zip) Please try this, it forces a two button mouse without wheel.

I've tried this too, and it still seems to be doing the same thing. I'm stumped. The little top mouse icon in the top-right flashes green and orange whenever I move the cursor, too.

No0ne, 2024-03-28:
The flashing icon is correct as it indicates the bus busy state.
Does it still scroll? The simulate mouse should not have a wheel at the moment.
Are you shure the uf2 is on the pico?
Do you have a usb serial adapter or another pico you can hook up to the serial tx pin?
I could build you a serial debug version for further testing.

naplesap, 2024-03-28:
> Does it still scroll? The simulate mouse should not have a wheel at the moment. Are you shure the uf2 is on the pico? Do you have a usb serial adapter or another pico you can hook up to the serial tx pin? I could build you a serial debug version for further testing.

The mouse wheel no longer works but it is somehow still scrolling when I move the cursor. I made sure to run [flash_nuke] before installing the latest uf2. I do have a spare pico.

No0ne, 2024-03-28:
Does the scrolling still happen if you plug the Startech mouse into a laptop?

naplesap, 2024-03-28:
> Does the scrolling still happen if you plug the Startech mouse into a laptop?

It seems to work fine when connected to a PC

No0ne, 2024-03-28:
🤔 Do you have a real PS/2 mouse? What happens if you connect it to the Startech and then to your device?

naplesap, 2024-03-28:
> 🤔 Do you have a real PS/2 mouse? What happens if you connect it to the Startech and then to your device?

I do not have an actual PS/2 mouse

No0ne, 2024-03-28:
If you try [pico-hid-1.0-pre.zip](https://github.com/No0ne/ps2x2pico/files/14789771/pico-hid-1.0-pre.zip) with the PC does scrolling work normal?

naplesap, 2024-03-28:
Is there any way possible to maybe use PS/2 keyboard simultaneously with the pikvm HID mouse output?

naplesap, 2024-03-28:
> > Is there any way possible to maybe use PS/2 keyboard simultaneously with the pikvm HID mouse output?
>
> You mean on the pikvm v4 without gpio?

Yes. I'm at a unique crossroads: My device has a video output of 1920x1080 60hz so I cannot get video on pikvm v2 but the mouse works perfectly. On V4 the video works but I'm having the mouse issues. haha

No0ne, 2024-03-28:
@mdevaev should know that

mdevaev, 2024-03-28:
> Is there any way possible to maybe use PS/2 keyboard simultaneously with the pikvm HID mouse output?

No, right now it's not possible.

naplesap, 2024-04-05:
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
Hey, sorry for the delayed reply. I was out of town for a couple days. Yes, my v4+ does have the jumpers shown in the picture.

naplesap, 2024-04-05:
> ![image](https://private-user-images.githubusercontent.com/164865558/320074806-ef61ae27-add1-429c-9c1b-e9b7a46f673f.png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) Hey, sorry for the delayed reply. I was out of town for a couple days. Yes, my v4+ does have the header shown in the picture.

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
However it appears they're used to connect to the top board:
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

No0ne, 2024-04-05:
Ha, this is working, just tested on my v4 mini! :)
For testing you have to leave the top board disconnnected as it routes the serial thru the RS232 converter to the RJ45 jack.

Jumper Pico GPIO22, 2 and 3 to GND (remove any other jumper).
Connect the Pico as shown in the photo bellow:
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

Add the following to your /etc/kvmd/override.yaml:
```
kvmd:
    hid:
        type: serial
        device: /dev/ttyAMA0
        reset_pin: -1
```

Remove the following from your /boot/cmdline.txt:
```
console=serial0,115200
```

Then you should have a PS/2 keyboard an USB mouse.

naplesap, 2024-04-05:
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

Just to confirm, I would use `pico-hid.uf2` on the pico, correct?

No0ne, 2024-04-05:
any of the uf2 should work, try the offical first

naplesap, 2024-04-06:
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

IT WORKS!!!! This is huge!! You have no idea how grateful I am!

No0ne, 2024-04-06:
Cool! I closed the issue with the two PIO USB devices then.

No0ne, 2024-04-06:
Cool! I closed the issue with the two PIO USB devices then.

May I close this one too?

naplesap, 2024-04-06:
Yes. Thank you so much for all of your help. It’s greatly appreciated. I’ll dig out the micrometer to see if I can plug this into the USB-C or RJ-45 ports.

No0ne, 2024-04-07:
On the USB-C port: No, theres a CP210n in the way!

On the RJ45: Maybe, theres a MAX232 in the way. You would need another MAX232 and four 10μF.

The easiest would be another pico running this: https://github.com/Noltari/pico-uart-bridge
And then connect GPIO16/17 from this to GPIO21/20 on the existing pico.

No0ne, 2024-04-09:
Ok I will look into the paste feature!

No0ne, 2024-05-19:
I checked that, it works if I make the output queue larger, but I don't know how much memory this needs on the pico.
How many character would you like to paste?

Closed 2024-06-14.

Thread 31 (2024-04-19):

Document cautions regarding current consumption

ssokolow, 2024-04-19:
Given that PS/2 ports are rated for 275mA, that older motherboards originally used non-resettable fuses, that there's no spec requirement for newer motherboards to use resettable fuses, and that some USB keyboards draw so much power that they require two 500mA USB A plugs to stay within specified limits (my brother has one), it'd be a good idea to document the DOs and DON'Ts in that regard.

(In my case, my solution was to hang the Pi (after programming but before soldering), the keyboard I plan to use, the mouse I plan to use, and the USB/VGA KVM switch this whole endeavour is for (my HP t5530 running Win98SE gives Fatal Error 0E if you unplug a USB HID device while it's running), which doubles as a three-port USB hub, off one of those cheap Chinese [Charger Doctor](https://www.ebay.ca/sch/i.html?_from=R40&_nkw=charger+doctor&_sacat=0&LH_BIN=1&_sop=15) voltmeter/ammeter things and I got a maximum observed current draw of 0.17 amps.)

No0ne, 2024-04-19:
True! I'll include that in the readme.

No0ne, 2024-04-19:
Updated README.md!

Closed 2024-04-19.

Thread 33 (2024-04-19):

[request] Troubleshooting Guide

ssokolow, 2024-04-19:
I just built what *should* be a functioning ps2x2pico, but it's not.

1. The pin assignments between it and the level shifter are all as described in the README.
2. It does show up for programming if I BOOTSEL, so the chip isn't dead.
3. The power LED does come on when it's being powered off its PS2 side by a PS2-to-USB adapter (I don't want to risk plugging it into the vintage machine until I trust it)
4. The USB Type-C OTG adapter does allow me to successfully plug the test mouse or test keyboard into a modern PC's USB Type C port and use them.
5. For the surrogate vintage PC, I've tested with both a $3 eBay PS2-to-USB adapter and a $20-30 ioGear adapter from 10+ years ago with the same Chesen chip used by [this high-quality StarTech adapter](https://www.amazon.ca/dp/B00028OP2Y) and both work fine with the test keyboard and mouse when talking to them directly.
6. I double and triple checked and couldn't find any solder bridges or places where I should be getting continuity but am not.

...but the test input devices just don't come up when I plug them into it via the USB OTG adapter and then plug it into the modern PC via the PS2-to-USB adapter for the smoke test. (The LED for the optical sensor on the mouse doesn't light, and the keyboard doesn't do anything)

I thought maybe these lines were indicative of Dolphin's file copying interacting badly with the Pi Pico's "reboot when it thinks you're done sending the firmware" behaviour...

```
[1269453.915631] device offline error, dev sdd, sector 260 op 0x1:(WRITE) flags 0x100000 phys_seg 1 prio class 2
[1269453.915636] Buffer I/O error on dev sdd1, logical block 259, lost async page write
[1269454.128385] FAT-fs (sdd1): unable to read boot sector to mark fs as dirty
```

...so I tried using `cp /home/ssokolow/inc/ps2x2pico.uf2 /media/ssokolow/RPI-RP2/` and `cp /home/ssokolow/inc/ps2x2pico_5628f15_200hz.uf2 /media/ssokolow/RPI-RP2/` instead, which did cut it down to this...

```
[1270597.093027] FAT-fs (sdd1): unable to read boot sector to mark fs as dirty
```

...but no change in results from either firmware version.

There needs to be some kind of guide to what to do next to diagnose "thing doesn't work but it doesn't appear to be an assembly problem".

(I have no experience with the RP2040. What minimal experience with microcontroller programming I do have is all Arduino Uno plus Arduino IDE and STM32 Blue Pill + STM32duino + cheap Chinese ST-Link clone... dammit, Jim, I'm a PC and web developer not a microelectronics guy! With things as they are, I'm basically just stuck tossing what should be a couple of pieces of electrical tape, a squirt of hot glue, and a few screws away from being a fully assembled and cased ps2x2pico into the closet and putting up with reaching for the rear of my two keyboards when I want to practice programming for Windows 98 SE.)

No0ne, 2024-04-19:
Hi! Can you hook up to serial port on GPIO0 with settings 115200n8, there should be debug output on boot and on usb events.

ssokolow, 2024-04-19:
Sure. Give me a sec to dig up a 3.3V-compatible USB-TTL Serial adapter and see if I can find my read-made test-clip leads for it.

ssokolow, 2024-04-19:
I just get `ps2x2pico-1.0<newline>` and that's it.

No0ne, 2024-04-19:
Mhm there seems something wrong on the USB side. Is 5V present? Try without a hub.

ssokolow, 2024-04-19:
That was with it powered from the PS/2 side via a USB-PS2 adapter and an un-hubbed mouse hanging off the USB side. However disconnecting everything except the GPIO0 test clip and then powering it off a USB C cable on the USB side doesn't appear to change anything.

No0ne, 2024-04-19:
Can you test with another USB device? Check if it is really powered.

ssokolow, 2024-04-19:
Define "with another USB" device. Am I supposed to be replacing the ps2x2pico with something else to test that the port is good, or am I supposed to be replacing the mouse to test that side of the equation?

...because I've already tried plugging the ps2x2pico into another port via a USB A-to-C cable so I could use my Charger Doctor to verify correct voltage and measure amperage. It wavers between 5.01V and 5.00V whether it's on one of my case's front-panel USB 3 ports or one of the USB 2 ports I exposed via a 3.5" bay, same as what the Charger Doctor reads when it's powering a USB-PS2 adapter to test powering it from the PS/2 side without putting any vintage tech at risk.

No0ne, 2024-04-19:
I ment different usb mouse or a usb keyboard. There should be a message on the serial output when a USB device is detected.

ssokolow, 2024-04-19:
I just tried plugging a second Charger Doctor in between the mouse and the ps2x2pico. While the ps2x2pico's power light is on, the Charger Doctor on the USB side either isn't getting any power or isn't getting enough power to turn on when powered from the PS/2 side.

ssokolow, 2024-04-19:
Give me a sec. I recently bought a cable to break out the power lines from a USB Type A into alligator clips. I'll grab my multimeter and see if it's getting voltage but not enough.

ssokolow, 2024-04-19:
Yep. Multimeter says there's 5.02V on the PC's USB Type A port, but only about 0.1V on the ps2x2pico's USB Type C port when powered from a PS2-to-USB adapter via VBUS. (It seems to be some kind of unregulated trace value because I've seen it crawl down from 0.17V and up from 0.08V.

No0ne, 2024-04-19:
mhm thats what I suspected. VBUS also feeds the USB micro port and VSYS only provides power for the pico itself.

ssokolow, 2024-04-19:
So you're saying the silkscreen on this board and the documentation I read have different opinions about whether VBUS or VSYS should be labelled as Vin?

No0ne, 2024-04-19:
Which RP2040 board do you have?

ssokolow, 2024-04-19:
A Chinese clone, because shipping on the name-brand ones was prohibitive for single-unit orders.

No0ne, 2024-04-19:
Then maybe this has a diode between Vin and the USB port and can't send power out the USB port.

ssokolow, 2024-04-19:
If getting VBUS and VSYS mixed up won't cause any permanent damage, I'd be willing to pull the soldering iron back out an try plugging the power into "Vout" to see if they labelled them backwards from the guides I read.

No0ne, 2024-04-19:
Ok! Seems to be related to this: https://github.com/No0ne/ps2x2pico/issues/22

ssokolow, 2024-04-19:
**EDIT:** As for the diode hypothesis, give me a sec to play around with the USB-Alligator lead and my multimeter.

No0ne, 2024-04-19:
Based on the photos in #22 Vout seems to be VBUS and Vin is VSYS so Vout should be right.

ssokolow, 2024-04-19:
I'll try it anyway, but I think there's also a diode. I'm getting an open circuit from the USB 5V line to Vout OR Vin in one direction but not the other.

ssokolow, 2024-04-19:
Hah! I just noticed that the duplicate silkscreens on the bottom include parenthesized `(VBUS)` and `(VSYS)` and Vout *is* VBUS. Give me a sec and I'll PR a fix for that change to the README.

No0ne, 2024-04-19:
I look at the PDF from #22 https://github.com/initdc/YD-RP2040/blob/master/YD-2040-2022-V1.1-SCH.pdf
Indeed Vout is also connected after the diode. So there seems no way to output 5V by connecting to VBUS on this board.

Does it work on your board now?

No0ne, 2024-04-19:
Or connect the PS/2 5V directly on the diodes VBUS leg.

ssokolow, 2024-04-19:
In both cases, I have to things to say:

1. Would that engender any risk to the devices it's plugged into? I'm kind of paranoid about that.
2. I'm gonna need a better magnifying glass</jaws_paraphrase>

(Seriously. This looks like it'll be a $4.60 opportunity to practice interacting with surface-mount components so small I can barely see that they *exist*... I'm glad my brother threw in a more SMD-sized tip when he bought me my Hakko as a Christmas gift.)

No0ne, 2024-04-19:
The only risk I can think is if you have plugged in PS/2 and USB to another computer for firmware upload.
This would short both 5V rails or worse if the PS/2 computer is powered of backpower that 5V via the pico, which is probably not good.

But if you always disconnect both PS/2 connections while firmware updating there sould be no problem.

ssokolow, 2024-04-19:
So basically the same caution as with the STM32 Blue Pill or Black Pill boards. (No protection between the USB connector and the power supply pin on the programming header you plug your cheap Chinese clone ST-Link into.)

Judging by the schematic, the least fiddly way to do this is to scrape away the solder mask between those two input legs on BAT54C, add some solder to bridge them together, and then move the wire back to Vin.

(The centre-ward leg is connected to the USB C and the edge-ward leg is connected to the Vin pin... on the opposite side of the board. It appears to do so by ducking in between the mechanical supports for the USB C port and passing under its body.)

ssokolow, 2024-04-19:
Nope. Looks like I just made it harder on myself. The now-exposed copper between them is ground plane.

ssokolow, 2024-04-19:
It took several false starts, including grinding the top of the Schottky off with my Dremel because it wouldn't lift, so I could use it as more not-overlapping-with-the-exposed-ground-plane pad to solder to, only for it to then lift because of the greater surface to receive heat, but I present my submission for the "Ugliest functioning ps2x2pico" contest.

(It still needs some electrical tape around those wire joints because I forgot to slip heat shrink on first, some clear nail polish over the concerningly-close-to-VCC patch of exposed ground plane, and the case I prepared for it, but it does work and, aside from having tested it with the USB-to-PS2 adapter instead of the repurposed HP t5530 thin client, it works in exactly the configuration I want to use it in.)

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

No0ne, 2024-04-19:
Thanks, I updated the Readme.md

Closed 2024-04-19.

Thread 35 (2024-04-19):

Mouse wheel input is ignored on some mice

ssokolow, 2024-04-19:
With `ps2x2pico.uf2` or `ps2x2pico-200hz.uf2` from the [Version 1.0](https://github.com/No0ne/ps2x2pico/releases/tag/1.0) release:

* The mouse wheel registers just fine on the Gateway pack-in mouse (Model: MOAKUO) that I was testing with in case I screwed up my assembly and fried something.
* The mouse wheel on the Acer pack-in mouse (Model: MOLDUO) that I actually use (better sensor that doesn't just give up on the white hardtop mouse pad I'm used to) has no effect
* Both mouse wheels work just fine when plugged into a PC with USB support

ssokolow, 2024-04-20:
Geez, I even commented in that thread. How tired *was* I?

Anyway, I just realized that I don't need the Acer so, since it's a known issue, unless you think it'd be helpful to the development effort for me to test it right now, I'd prefer to wait until you have a "Release Candidate. Needs compatibility testing" build based on something at least as new as the v1.0 200Hz that I'm running.

(The mouse I *really* wanted to use is my Logitech G203 Prodigy so I have only *one* mouse on my desk, and its scroll wheel works fine with the ps2x2pico, but it's a bit picky and sometimes becomes non-responsive after toggling my "I emulate enough USB HID to notice when the scroll lock LED blinks" USB/DVI KVM switch. Now that I've got a brainless USB switchbox in front of it to bridge in the ps2x2pico, I can easily reset the mouse without reaching behind the desk if it decides to crash.)

No0ne, 2024-04-20:
Please test your mouse with the non-working wheel with this: https://github.com/No0ne/ps2x2pico/raw/24-ps2-input/ps2x2pico-report.uf2

ssokolow, 2024-04-20:
Wll do... though probably after I've gone back to sleep.

The ps2x2pico is now installed in place on the underside of my desk with the cables routed, so it's now a hassle to disconnect the PS/2 side so it's safe to reprogram, awkward to disconnect the USB side so I can reprogram it, and then a hassle to hook it back up to the PS2-USB adapter I prefer to use when testing new firmware.

...maybe I should order another YD-RP2040 and another M-M PS/2 cable to cut up and build another ps2x2pico for the next time I need to test a new firmware.

No0ne, 2024-04-20:
PS/2 is a little bit hotpluggable. It works under Windows for example, the Pico sends a 0xAA (BAT successful) on both ports and Windows then reinitializes keyboard an mouse new everytime.

ssokolow, 2024-04-20:
"Not hot-pluggable" in the sense of "multiple guides I've read tell you not to do it because it's sufficiently 'not in the spec' that, depending on the device, you run the risk of blowing that potentially non-resettable fuse".

For example, this passage from the [document](https://www-ug.eecg.utoronto.ca/desl/nios_devices_SoC/datasheets/PS2%20Protocol.htm) I recommended for its pinout diagrams:

> Vcc/Ground provide power to the keyboard/mouse.  The keyboard or mouse should not draw more than 275 mA from the host and care must be taken to avoid transient surges.  Such surges can be caused by "hot-plugging" a keyboard/mouse (ie, connect/disconnect the device while the computer's power is on.)  Older motherboards had a surface-mounted fuse protecting the keyboard and mouse ports.  When this fuse blew, the motherboard was useless to the consumer, and non-fixable to the average technician.  Most newer motherboards use auto-reset "Poly" fuses that go a long way to remedy this problem.  However, this is not a standard and there's still plenty of older motherboards in use.  Therefore, I recommend against hot-plugging a PS/2 mouse or keyboard.

ssokolow, 2024-04-20:
> Please test your mouse with the non-working wheel with this: https://github.com/No0ne/ps2x2pico/raw/24-ps2-input/ps2x2pico-report.uf2

Tested.

The first time I plugged it in, the cursor drifted to the right edge of the screen at a fixed rate, ignored horizontal movement, and then when i moved the mouse up and down, it appeared to inverse-scroll the scrollbar that happened to be below the cursor but I forgot to examine what it was doing more closely.

The second time, it drifted right for a few hundred pixels, then started to function in a way that appears normal and fully functional (including the wheel) except for the cursor movement being a bit glitchy. (It's hard to be sure, but I think it's that 'counter overflows when moving faster than a certain threshold' bug I remember being mentioned previously.)

No0ne, 2024-04-20:
Ok thanks, yeah I'll have to do the HID parser.

ssokolow, 2024-04-20:
I'll also need to get that test clip and USB-TTL Serial adapter out again once it's not so late in my day. It seems that something about testing and then flashing back to the firmware I remembered having on it before has it crapping out when I KVM switch away and back.

At the moment, the behaviour is:

1. If I want it to work, I have to set the KVM switch to make the input devices visible before I power on the PS/2 side. (It was always like this)
2. If I KVM switch away and back after it's started, the Logitech G203 Prodigy stops responding but the keyboard comes back fine.
3. If I KVM switch away and back again, there's at least a chance (I only tried it once) that I'll also lose the keyboard.

In any of those failure modes, un-plugging and re-plugging the USB side doesn't fix things and never has.

No0ne, 2024-04-20:
If you want to debug this I can make you a version which also prints out PS/2 bytes on the serial debug.

ssokolow, 2024-04-20:
I'd appreciate having access to it, but, given my degree of mental fatigue right now, I can't say whether I'm willing to commit to actually using it until I've had some rest.

...especially since I tried it again when I forgot to start `miniserve` on my Linux machine *before* booting up Win98SE and, this time, it worked fine... which means there's some variable I'm going to need to pin down in order to reproduce it reliably.

(eg. Maybe the success cases were all ones where I waited until the mouse began the "I've booted up. Let me celebrate before I apply your 'LEDs off' saved setting" animation cycle before I tried touching the keyboard or mouse, while the failure cases had me jumping the gun in some way? That might explain the mouse going first and then the keyboard the next time. Without the mouse celebrating the dawn, it's hard to tell when the keyboard will have finished initializing without counting seconds.)

...I suspect I'll probably say "yes" though. Half the reason the ps2x2pico interests me is that it's more idiot-proof than the USB4VC (the other half is because it's, to quote Douglas Adams, "slightly cheaper") and I've already ordered a USB Type C Male to Type B Male cable to take the USB OTG adapter out of the equation as a potential point of failure. Diagnosing this would fit with that.

ssokolow, 2024-04-22:
Yeah, I'll do it. I'll have to fit it in around whatever else is going on, but I'll do it.

ssokolow, 2024-04-23:
I just realized that might be unclear. It's a "Yes, please offer up the build at your earliest convenience." I just meant that, depending on what comes up, there might be 12-24 hour gaps in my testing."

No0ne, 2024-04-24:
Lets continue that in #36 and leave this for the HID parser so that all mouse wheels are working.

No0ne, 2024-11-05:
The latest pre-release should fix this: https://github.com/No0ne/ps2x2pico/releases/tag/pre-1.3

hax0rbana-adam, 2024-11-07:
I can confirm, this pre-release did fix the scroll wheel issue with my mouse (which didn't work properly before). I tested both the compiled release and compiled it myself from source. Well done. :clap:

No0ne, 2024-11-08:
Thanks for testing!

Closed 2024-11-08.

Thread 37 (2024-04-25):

ps2x2pico initializes too slowly to be able to enter BIOS

ssokolow, 2024-04-25:
I just messed up the Win98SE install on my HP t5530 and, when I held F12 for "force netboot to the top of the boot order" to access my homebrew "Apple Internet Restore for DOS/Win9x PCs" so I could restore my backup, I discovered the hard way that none of those BIOS "hold X to Y" keys work, whether on a cold boot or if I warm boot via Ctrl+Alt+Del.

I'm not sure if this is fixable, but maybe there could be some kind of workaround where the ps2x2pico remembers whether a function key or Delete was being held down before a warm reboot and persists that state on the PS/2 side to the PC until USB device initialization completes and it has fresher data?

ssokolow, 2024-04-26:
There's only about a 1-second window when the BIOS is listening for keystrokes, if that. It's an early example of the "Don't worry about stuck key warnings. Just hold the key down while powering on to avoid missing the window." design you tend to see with UEFI.

No0ne, 2024-04-26:
Ok yes, but this should only matter on cold boots and not reboots. I don't think we can get this any faster. You will need to supply power otherwise so that its on before the PC.

ssokolow, 2024-04-26:
Holding F12 and then clicking to reboot from inside Windows 98 SE works to pull up my netboot environment with a genuine PS/2 keyboard but not with the ps2x2pico.

No0ne, 2024-04-26:
Ok hm 🤔 that should work though. I'll build you a debug version for this problem.

No0ne, 2024-04-26:
Yes, command 0xff and response 0xaa is implemented, I'll check if I can get a t5530 for debugging.

No0ne, 2024-04-26:
Got one for 35 euros so I can check for my self 🥳

bstrobel, 2024-04-26:
Your right. I just checked the diff and refreshed my memory. The project is 10y old and I did the fix 5y ago. How time flies... Anyway the bug was that I didn't send 0xfa (ACK) before sending the device id. I checked your code and you are doing that correctly. So no difference to what I did at the time.

Just wanted to say Thank you for this great little project. I always wanted to do something like that and never found the time. Great Work! :+1:

No0ne, 2024-04-26:
Should be the same: https://github.com/No0ne/ps2x2pico/blob/486a5950fcf86650e9b1b41b5542cac5ca1523e7/src/ps2kb.c#L238
I'll check when the t5530 arrives next week.

ssokolow, 2024-04-26:
> Got one for 35 euros so I can check for my self 🥳

Enjoy. It makes an excellent fanless late-Win98SE-era machine if you eBay a bigger ATA disk-on-module, install the appropriate drivers off VIA's website, and either use a USB CD-ROM drive or install a period-appropriate copy of DAEMON Tools.

Heck, the only reason it's not the greatest for earlier stuff is that the onboard audio doesn't have native Soundblaster compatibility and it doesn't have an ISA or PCI slot to stick a genuine SoundBlaster into.

It's even got VESA mounting holes so you can hang it off the back of a monitor.

No0ne, 2024-05-11:
Still waiting on the t5530 order, but I haven't had time anyway at the moment.

bstrobel, 2024-05-16:
@ssokolow When working on issue #38 I refactored the code a bit and streamlined the host to keyboard communication. I don't think that the Pico initializes too slowly to be honest. If you want you could try the new version I created. I have attached it here:
[ps2x2pico.zip](https://github.com/No0ne/ps2x2pico/files/15332544/ps2x2pico.zip)

If you can it would be good if you would connect a serial terminal to the debug output and post the logs here. I would clarify what is going wrong. Each host has its own way of communicating and configuring the ps/2 keyboard. I tried and traced with a few and each one was different. Maybe yours is especially picky?

ssokolow, 2024-05-17:
I'll give it a look as soon as I've made time for retro-hobby stuff again. The last week or so has been pretty busy with spring cleaning and the like.

No0ne, 2024-05-19:
Finally got the t5530 and I found two potenial issues:
If the key is held down before tinyusb is running it may not be detected,
and (I think thats the real problem) if the host resets the keyboard (while rebooting) the repeating key is also resetted.
It works if you don't hold the key but mash it multiple times, but I think it should also work holding it down, yes!

No0ne, 2024-05-19:
Finally got the t5530 and I found two potenial issues:
If the key is held down before tinyusb is running it may not be detected,
and (I think thats the real problem) if the host resets the keyboard (while rebooting) the repeating key is also resetted.

It works if you don't hold the key but mash it multiple times, but I think it should also work holding it down!

And yes, the bios routing of the t5530 is really fast, did not see any bios this fast before.
As an alternative if you set 5sec POST delay in the bios it also works well.

I'll look into it that it works with holding the key down!

No0ne, 2024-05-19:
I think I got this, its working by holding down F10 or F12 on my t5530 without POST delay and quickpost enabled.
@ssokolow please try this: [t5530-fix.zip](https://github.com/No0ne/ps2x2pico/files/15369643/t5530-fix.zip)

ssokolow, 2024-05-21:
Will do. The last few days have been busy but I should have free time starting on Wednesday.

ssokolow, 2024-05-24:
Sorry I went silent. I bruised a rib the afternoon after I said "Will do" and it took me until now to be physically able to get under my desk to access the ps2x2pico.

It's now sitting on top of the desk where I can comfortably work on it and I should be able to make time to test it either today or within the next couple of days.

ssokolow, 2024-05-27:
So far, I literally haven't tested anything but the F10 and F12 keys the Ctrl+Alt+Delete key combo yet, but `t5530-fix.zip` does let me access the BIOS and force netboot on both a cold boot and a Ctrl+Alt+Delete warm boot by holding down the relevant key.

No0ne, 2024-05-29:
Cool, thanks for testing. So is this issue fixed now?

ssokolow, 2024-05-29:
Yes. As far as I can tell, `t5530-fix.zip` fixes it perfectly.

Thanks. :)

Closed 2024-05-29.

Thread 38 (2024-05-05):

SGI O2 Ctrl acts as CAPS Lock - Scan Code Set 3 not supported

bstrobel, 2024-05-05:
I have 2 SGI O2s that work well with any standard PC PS/2 keyboard that I have. When connecting them to my `ps2x2pico` adapter everything seemed to work until I pressed the Ctrl key. It acts as if it were the CAPS Lock key.

To debug this issue I connected a serial debug terminal and added these log messages in `ps2kb.c`
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

I found out that the O2 requests Scan Code Set 3:
```
...
kb_receive(byte = f0, prev_byte = f5)
kb_send(byte = fa)
kb_receive(byte = 3, prev_byte = f0)
kb_send(byte = fa)
...
```

This corresponds to the observed behaviour since make code 0x14 is Ctrl in Scan Code Set 2 and Caps Lock in Scan Code Set 3.The former is the one that is widely used and also used in your translation table in the code I assume.

So to support such old and rare hardware the proper selection and mapping of the 3 scan code sets should be implemented. I assume there is more fancy retro equipment out there that does similar things

If you're ok with it, I can do this. But no problem if you want to implement this yourself.

No0ne, 2024-05-06:
Ah ok, I don't have any machines that request scancode set 3, so thats why its not implemented. But I think this should be fairly easy as only the mapping arrays must be swapped.

I'm currently out of freetime, feel free to send a pull request. If not I'll implement this eventually but can't say when.

bstrobel, 2024-05-06:
Ok, I just wanted to make sure that we don't do double work. So I will work on that.

BTW It seems there are more problems SGI and/or scan code set 3 related. Typematic repeat doesn't work. After 4 repeated characters the O2 just sends a reinit sequence to the keyboard and only prints 2 of the 4 characters. I analyzed it with a logic analyzer and ps2x2pico seems to do everything correctly as far as I can see.

All of this works with an old PC keyboard though. My plan is to use the LA to analyze the communication with this kb and see what needs to be implemented how. The issue is the PS/2 decoder in PulseView is broken. I think I will need to fix this first.

I googled a bit about this topic and it seems the scan code set 3 behaviour has a few more differences than just a different mapping. It was the "real" PS/2 mode and was probably made intentionally incompatible to the original PC as the whole PS/2 computer system was meant to be. And SGI picked it up obviously.

I also don't have a lot of time to spare but I'm also very keen on getting the O2s connected to the KVM. So please be patient. :)

bstrobel, 2024-05-08:
I'm currently working through your code and the tinyusb examples to make sense of it before I actually start to implement my changes.

I have a few small questions.
1. You explicitly check for 0 in the report[1] field which is reserved:
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
This means you ignore all reports that have this field set to something else than 0. This looks to me as if you wanted to filter out some erroneous messages. Do you have any documentation on this or why are you doing this?
2. I'd like to add a few debug outputs which could be quite verbose and thus could potentially impose performance degradations (no idea how serial output is handled in the Pico). That's why I'd like to wrap them in a \#ifdef TRACE or something. You ok with that?
3. Since I'm in the 'scan code set change business' anyway I will also add Scan Code Set 1 just for completeness. But I have no hardware to test this. Ok?

Scan Code Set 3 has few extended features that are also utilized in part by SGI. For instance it is possible to disable BRAKE codes and typematic *per key*. Also BRAKE codes are handled differently and there are no extended codes. I will implement everything according to the documentation and test with the SGI O2. This also means more code changes than you might have expected.

Please let me know what you think

No0ne, 2024-05-11:
Sorry for the late reply, I'm currently really out of time :(

1. Don't remember where I read about this second byte being zero. Maybe this check is wrong, you may remove it.
2. No problem, just add debugging stuff.
3. Yeah no problem, the more feature complete, the better!

Did not read any Scan Code Set 3 stuff, but theres also stuff which alters repeat and break codes in Set 2 which is not yet implemented.

bstrobel, 2024-05-14:
Thanks NoOne! :) In the meantime I implemented set 3 and and set 1 and did a bit refactoring. I smoke tested it with my Pentium PC and my SGI O2. Seems everything works so far. I think there is some more things to investigate and correctly, like media keys, Europe1 and Europe2 keys in set 3, host command resend (0xfe) which is unclear how it should work in reality. All of this should improve compatibility.

Here is my code: [fork of your repo](https://github.com/bstrobel/ps2x2pico/tree/scancodeset3?tab=readme-ov-file) I didn't issue a pull request yet since I think it needs a bit more work before being merged.

I also added a lot of debug messages that are quite helpful in my eyes. I think they are also helpful if other people are having problems and we're asked for help. For instance the vendor name and device name are printed in clear text along with the vid and pid of the device when mounted.

This could help identifying the problem when using usb kvm switches. For instance the problem with my kvm switch had a quite unexpected source. I have a cheap VGA2HDMI converter which needs power from USB to work. The quick solution was to connect its USB plug to the kvm switch which has 4 ports. This works in general but I it was causing the issues with ps2x2pico! I didn't know that this USB plug is not only carrying the power lines but is fully featured. The VGA2HDMI adapter registers on USB as a mass storage device without a connected media and a HID device. Seems this is a weird firmware update interface (or something vicous... :) ). Anyway it prevents ps2x2pico from working. Maybe we should think of vid/pid blacklisting?

Another example: I connected a Logitech USB receiver to ps2x2pico expecting it to be just one device. But this is what ps2x2pico sees:
```
HID(1,0,KEYBOARD) mounted
 ID: 046d:c52b
 Manufacturer: Logitech
 Product:      USB Receiver

HID(1,1,MOUSE) mounted
 ID: 046d:c52b
 Manufacturer: Logitech
 Product:      USB Receiver

HID(1,2,NONE) mounted
 ID: 046d:c52b
 Manufacturer: Logitech
 Product:      USB Receiver

HID(2,3,KEYBOARD) mounted
 ID: 413c:2003
 Manufacturer: Dell
 Product:      Dell USB Keyboard

```
So it registers in fact as 3 devices although only a mouse is connected. The Dell keyboard is in fact a real keyboard.

I didn't change anything essential on the usb side of things, just the logs. I upgrade tinyusb lib to the latest release version 0.16.0. Initially I had checked out master but I went back to the release version when I experienced strange behaviour. It mostly works but occasionally I get messages like
```
[0:1] Control STALLED, xferred_bytes = 0
21 0A 00 00 01 00 00 00
```
from tinyusb (these are not my log messages!). I didn't investigate yet what it means.

In my fork I added a few links in Readme.md to a resource that I used in earlier projects. It describes the usage of set 3 better and has decent set 3 table.

Anyway it is quite fun to work on this and it is cool to work on the O2 with a decent keyboard. :D

No0ne, 2024-05-17:
Thanks for the PR, is this issue now fully resolved?

bstrobel, 2024-05-19:
Yes, the issue is resolved.

No0ne, 2024-05-19:
very cool, thanks for the support!

Closed 2024-05-19.

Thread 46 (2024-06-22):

Use this with Mouse Only?

lnxsrt, 2024-06-22:
Is it possible to use this only for the Mouse? I have a PS/2 keyboard and would like to use this for the Mouse only.

I'm seeing it register my USB mouse in the debug messages on GPIO0, but the machine does not recognize it.

No0ne, 2024-06-22:
Yes should work with only the mouse! Please post the debug messages.

lnxsrt, 2024-06-22:
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

No0ne, 2024-06-22:
Looks ok yes, please post a picture of the hardware and connections.

lnxsrt, 2024-06-22:
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

No0ne, 2024-06-22:
Also seems ok, which motherboard and OS do you have?

lnxsrt, 2024-06-22:
I've tried on my 2 socket 7 boards (P/I-P55T2P4 and a GMB something). DOS with ctmouse and Windows 98SE. Neither work. Both work fine with a PS/2 mouse.

lnxsrt, 2024-06-22:
Also just continuity checked again and everything matches the pinouts, no shorts, etc.

No0ne, 2024-06-22:
Huh, thats interessting!
I just checked with my HP t5530, this works with only the mouse.
But on my Gigabyte GA-5AX Socket 7 the mouse does not work without a ps/2 keyboard connected 🤔

So I think this is more like a motherboard problem?

lnxsrt, 2024-06-22:
It doesn't work without a ps2x2pico PS/2 keyboard (ie USB)?

I have a PS/2 keyboard connected, just not through the ps2x2pico.

No0ne, 2024-06-22:
Ok strange, I think thats a different problem then. I'll send you a more verbose debug version.

No0ne, 2024-06-22:
Please post the serial debug of this version:
[mousedebug.zip](https://github.com/user-attachments/files/15938215/mousedebug.zip)

lnxsrt, 2024-06-22:
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

No0ne, 2024-06-22:
Ok theres something wrong with the hardware, we don't get any bytes from the PC.
Should look like this:
```
HID(1,2,NONE) mounted
 ID: 1532:0098
 Manufacturer: Razer
 Product:      Razer DeathAdder Essential

host > ms ff
ms > host fa
ms > host aa
ms > host 00
** ps2in reset sm 01
host > ms ff
ms > host fa
ms > host aa
ms > host 00
** ps2in reset sm 01
host > ms ff
ms > host fa
ms > host aa
ms > host 00
** ps2in reset sm 01
host > ms e8
ms > host fa
host > ms 00
ms > host fa
host > ms e6
ms > host fa
host > ms e6
ms > host fa
host > ms e6
ms > host fa
...
```

Is clock and data mixed up?

lnxsrt, 2024-06-22:
Ok, so I re-checked continuity on all of the HV side levelshifter connections to the PS/2 socket. Everything is good there. But, this time I also checked continuity from the resistors on the levelshifter to the pins on the levelshifter. Turns out the mouse data LV side was not connecting the the resistor on the levelshifter board. The trace had somehow lifted or something. Reflowed that connection, confirmed continuity, and it is working now.

Thanks for the help! Never thought the levelshifter would have a funky trace.

No0ne, 2024-06-22:
Cool! Thanks for debugging :) Now I'll need to check my Socket 7 board 😆

Closed 2024-06-22.

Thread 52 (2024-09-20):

Mouse not working on 486, is working on Pentium 3

rmpel, 2024-09-20:
Hi. First off; fantastic project!

I have a question though; I don't seem to get the mouse working on my 486 computer.
It is working perfectly on my Pentium 3 laptop, however, the intended use case is on my 486 and 386 computers. On both, the mouse is not recognised.

Keyboard works perfectly.

I checked the wiring, it is all correct (of course, as it works on the P3 computer), I also tried the two alternate firmwares with fixed polling rates.

Tested with 4 mice, the mouse in the debug log below is a Dell branded Logitech mouse, and I also tested a Commodore Tank Mouse imitation (The one intended for the "The C64"), a Logitech MX something or other wireless and my Razor Viper Ultimate.
I have not used the serial debugging with the latter 3, but they respond the same on both computers as the Logitech. (they all work on the P3, none of them on the 486)

Debugging output on the 486 (dedicated mouse port, according to the case labeling);
```
ps2x2pico-1.2
Setting defaults for keyboard
scancodeset set to 2
** ps2in reset sm 00
kb > host aa
** ps2in reset sm 01
Blinking keyboard LEDs
HID(1,0,MOUSE) mounted
 ID: 046d:c077
 Manufacturer: Logitech
 Product:      USB Optical Mouse

HID(1,0,MOUSE) registered for reports
```

And on the pentium 3 (combined mouse/keyboard port);
```
ps2x2pico-1.2
Setting defaults for keyboard
scancodeset set to 2
** ps2in reset sm 00
kb > host aa
** ps2in reset sm 01
Blinking keyboard LEDs
HID(1,0,MOUSE) mounted
 ID: 046d:c077
 Manufacturer: Logitech
 Product:      USB Optical Mouse

HID(1,0,MOUSE) registered for reports
** ps2in reset sm 01
```

The only difference is the line;
```
** ps2in reset sm 01
```
at the end.

In both cases, there is no further output. I don't know if it should, but there is no indication of mouse movement or button clicking in the serial log.

Unfortunately, this knowledge doesn't help me solve the problem, so I hope you can give some pointers.

Thank you in advance :)

Remon.

rmpel, 2024-09-20:
Hi, thanks for responding :)

OS: MS-Dos 6.22, Win 3.11, DR DOS 6.0
Driver: any. (Logitech, cutemouse, microsoft mouse)
Mainboard: [Acer A1GX](https://theretroweb.com/motherboards/s/acer-a1gx).

I am quite sure OS and Drivers are not the issue, as the BIOS upon init already tells me "No pointing device" and when I have a PS/2 mouse connected "Pointing device installed".

No0ne, 2024-09-21:
[pre-1.3.zip](https://github.com/user-attachments/files/17083570/pre-1.3.zip)
Please post the serial output of the pre-1.3 version, it has more mouse debugging, thanks!

rmpel, 2024-09-21:
Hi.

On the 486;

```
ps2x2pico-1.3
Setting defaults for keyboard
scancodeset set to 2
** ps2in reset sm 00
kb > host aa
ms > host aa
ms > host 00
** ps2in reset sm 01
Blinking keyboard LEDs
HID(1,0,MOUSE) mounted
 ID: 046d:c077
 Manufacturer: Logitech
 Product:      USB Optical Mouse

HID(1,0,MOUSE) registered for reports
```

Bios reports "point device none", driver says, no mouse, 100% like before.

On the Pentium 3;

```
ps2x2pico-1.3
Setting defaults for keyboard
scancodeset set to 2
** ps2in reset sm 00
kb > host aa
ms > host aa
ms > host 00
** ps2in reset sm 01
Blinking keyboard LEDs
HID(1,0,MOUSE) mounted
 ID: 046d:c077
 Manufacturer: Logitech
 Product:      USB Optical Mouse

HID(1,0,MOUSE) registered for reports
host > ms f5
ms > host fa
host > ms f2
ms > host fa
ms > host 00
host > ms ee
ms > host fa
host > ms ff
ms > host fa
ms > host aa
ms > host 00
** ps2in reset sm 01
```
followed by a lot of
```
ms > host 04
host > ms f3
ms > host fa
host > ms 64
ms > host fa
host > ms e8
ms > host fa
host > ms 03
ms > host fa
host > ms f4
```

No0ne, 2024-09-21:
hm, thats odd, has to do with timings 😟
do you have a logic analyzer at hand?

No0ne, 2024-09-21:
I made the output clock slower by 50%, just a shot in the dark.
[slowclk.zip](https://github.com/user-attachments/files/17083888/slowclk.zip)

rmpel, 2024-09-21:
Well, it does more, but no solution yet :(

```
ps2x2pico-1.3-slow
Setting defaults for keyboard
scancodeset set to 2
** ps2in reset sm 00
kb > host aa
ms > host aa
ms > host 00
** ps2in reset sm 01
Blinking keyboard LEDs
HID(1,0,MOUSE) mounted
 ID: 046d:c077
 Manufacturer: Logitech
 Product:      USB Optical Mouse

HID(1,0,MOUSE) registered for reports
host > kb ff
KBHOSTCMD_RESET_FF
Setting defaults for keyboard
scancodeset set to 2
** ps2in reset sm 00
kb > host fa
kb > host aa
Blinking keyboard LEDs
host > kb f2
KBHOSTCMD_READ_ID_F2
kb > host fa
kb > host ab
kb > host 83
host > kb ed
KBHOSTCMD_SET_LEDS_ED
kb > host fa
host > kb 02
kb > host fa
```

Reg a logic analyzer; no, I don't, sorry. I have a very simple handheld scope (multimeter combo), but I don't think that will help much.

rmpel, 2024-09-21:
I connected the kb here, let me do a new test with just the mouse port connected, i think most in above is not mouse related.

rmpel, 2024-09-21:
Yeah, as expected. I will cleanup my responses for future reference and avoidance of confusion

rmpel, 2024-09-21:
I see five things of note in that topic;
1. Question if the Data and Clock are swapped; they aren't (confirmed by multimeter and by working on P3 laptop)
2. Question about continuity; continuity is tested and approved (this also by multimeter and working P3)
3. Suggestion that a KB present or not makes a difference; it does not, both a real PS/2 keyboard as well as a ps2x2pico keyboard
4. Concern on correct function of the level shifter; considering the P3 works, I think it safe to assume the level shifter is working properly (as mouse is working on the P3).
5. A different firmware; just to avoid the "should I try, yes, try" delay; tried that fw, no difference.

To confirm; I hope to keep the information here as on-topic as possible, but the 386 has been tested in each case as well and responds the same as the 486, so no need to duplicate all that data, but just know that the 486 is not the only one I test :)

rmpel, 2024-09-21:
Oh, just remembered, I should also have a 486 laptop somewhere, I haven't tested on that one, I'll have to dig it out, will do so if you need the 4th test-case ;)

No0ne, 2024-09-21:
Sorry, don't know whats wrong here :( Could you create some scope traces? Maybe I can see something.

rmpel, 2024-09-21:
I'm sorry, I tried, but unfortunately, I can't.
The record function of my scope seems to only record for 10 frames at 100ns interval, and I cannot get it to record at the exact time the computer powers on.

I havent had my scope for that long, I don't know how to operate those functions. My scope skills are practically non-existent.

I've also dug through the code, added more debug output, but all I can say is that the 486 is not sending the same commands as the P3 seems to do. Could the 486 use an older variant ps/2 protocol? Is there a way to fake the handshake and just go ;)

i tried faking receipt of 0xFF and 0xF4, but that doesn't help. I haven't found out yet how to fake the entire sequence I see on the p3, being 0xF5 0xF2 0xEE 0xFF

the reason I tried F4 is because the code then should "Enable data reporting" according to the comments, but maybe I don't know what that means ;) ( Is "data reporting" mouse movement, or config data...)

I also tried to use commands to the ps/2 port using debug to try and get the mouse to respond, but the instructions I get from ChatGPT don't work well (instead of mouse being disabled and reenabled, my keyboard gets disabled, with, well, unhelpful results ;)

I haven't found a bios upgrade for my computer (not the 486 and also not the 386). If only I was more skilled in assembly, perhaps I could debug the BIOS to find out why the initialisation sequence isn't running. (I assume, even a 486 will want to know what mouse is present, so it should send F5 F2 at least...)

I appreciate the time and effort you have put into this and I'm sorry I'm not of much help.

No0ne, 2024-09-21:
As far as I know there are no protocol variants. The only thing which comes to mind is that I pushed the clock to the upper limit to achieve 200Hz polling under WinXP and up.

F4 Enable data reporting means mouse movement, right.

You can search for 8 channel logic analyzer, you can get one for under 10 euros.
If you want to debug this I think this is the only way. I used [Logic2](https://www.saleae.com/pages/downloads) and a cheap anlayzer for development.

rmpel, 2024-09-21:
Aight, I have a plan, but it will take some time
step 1, get a logic analyser
step 2, build an interposer (i have all the parts, just needs some soldering) to hook up de LA
step 3, learn how to use the LA and decode the PS/2 serial messages
step 4, capture and document the boot up sequence of the P3 (working) and the 486 (non working) ps2x2pico as well as a real mouse on both.

Step 1; I ordered this one `
https://www.amazon.nl/-/en/Youmile-Analyzer-Device-Channel-Arduino/dp/B09BTT94PC`
Says on the page it is compatible with saleae software, which is the program you linked above.
Will be here next week, but it will probably not be before next weekend until I get any kind of result ;)

Thanks again!

To be continued.

rmpel, 2024-09-22:
Step 2 done; interposer ready. (Cables not shown in photo ;)
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

( The PS/2 breakout boards are wired as Keyboard from factory, cut traces, rewired to the mouse pins )

No0ne, 2024-09-22:
Ah you have nice breakout boards, I just cut PS/2 extension cords 😂

rmpel, 2024-09-22:
Yeah, I got them to create dummy ISA card. The idea was (and still is) to expose 2 USB and 2 PS/2 ports at the back of the 486, allowing plugin in USB KB and Mouse and short PS/2 cables from the ports to the mainboard (maybe in future, if I feel brave enough, connect the PS/2 signalling directly to the mainboard.).
The mouse not working is a real spanner in the works. But I am hopeful we can get this fixed.

rmpel, 2024-09-27:
maybe found something. I think I interpreted the wiring diagram wrong

pins 2 and 6 are Mouse ... ON DUALPORT and normally not, I guess...

rmpel, 2024-09-27:
Confirmed. My own stupidity was causing the problems.

Turns out, the pentium 3 listens for mouse signals on both the normal and the alternate pins ... I will have to check, but it's probably a dualport without advertising it.

The 486 now has a USB keyboard and Mouse ;)

Very sorry for all the time wasted.

No0ne, 2024-09-27:
Ha, thats cool, I never thought that normal motherboards are wired for that. Only saw the dualport on notebooks and embedded systems.

Hope you'll find the logic analyzer useful anyway!

Closed 2024-09-27.

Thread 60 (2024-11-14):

Mouse not working on combination PS/2 port

Justasic, 2024-11-14:
Hello,

I have a combination PS/2 Mouse/Keyboard port on my motherboard and as such I have just soldered a single male connector to the pico. I plugged a keyboard into a USB hub which uses an OTG cable on the pico. The keyboard works perfectly as expected but when I try to use a USB mouse, it does not. If I plug a USB mouse directly into the OTG connector, it still does not function.

I connected to the serial console and I can see the keyboard is recognized and sends bytes on button presses but when I do the same with a mouse (even without a USB hub) I see it recognize the mouse as a USB device but it doesn't specify the manufacturer or product, it also does not send any data to the host when I move the mouse or click it's buttons.

I have tried at least 5 different brands/models of mice to confirm that this isn't a model-specific issue but all of them report no manufacturer, no product, and don't function or show any information about being recognized outside of stating it's registered a new USB device.

Is there something I'm doing wrong or can test to debug further? I tried using the ps2x2pic version 1.2 100 Hz, the standard version 1.2 and the pre-release version 1.3 to see if that changed anything and unfortunately it did not.

Thanks!

No0ne, 2024-11-14:
Please try the new 1.3-pre release: https://github.com/No0ne/ps2x2pico/releases/tag/pre-1.3

No0ne, 2024-11-14:
Which exact models have you tested?

Justasic, 2024-11-14:
Tested mice:
- Lenovo MOJUUO
- Microsoft "Optical Mouse Blue USB and PS/2 Compatible" (no model, has a P/N of X08 - 72983)
- HP gaming keyboard and mouse (mouse only was tested) km100
- Microsoft basic optical mouse v2.0 model 1113
- "Optical Mouse" M700 (seems like a generic no-name brand)

I work in a PC shop so I have access to many more mice if necessary. I used the 1.3-pre for testing all of these.

The serial console output looks like this for each of them.
```
HID(1,0,KEYBOARD) mounted
 ID: 045e:0752
 Manufacturer: Microsoft
 Product:      Wired Keyboard 400

HID(1,0,KEYBOARD) regystered for reports
HID has 1 reports
HID(2,1,MOUSE) mounted
 ID: 045e:00cb
 Manufacturer:
 Product:

HID(2,1,MOUSE) registered for reports
HID(2,1) unmounted
HID has 1 reports
HID(2,1,MOUSE) mounted
 ID: 1c4f:0034
 Manufacturer:
 Product:

HID(2,1,MOUSE) registered for reports
HID(2,1) unmounted
HID has 1 reports
HID(2,1,MOUSE) mounted
 ID: 1c4f:0048
 Manufacturer:
 Product:

HID(2,1,MOUSE) registered for reports
HID(2,1) unmounted

```

No0ne, 2024-11-14:
🤔 I have a mouse with the same IDs which works:
```
HID has 1 reports
HID(1,0,MOUSE) mounted
 ID: 045e:00cb
 Manufacturer: PixArt
 Product:      Microsoft USB Optical Mouse

HID(1,0,MOUSE) registered for reports
```
Which Pico board do you have?

No0ne, 2024-11-14:
Did you try the new pre-release I posted minutes ago?

Justasic, 2024-11-14:
Alright, I installed the pre-release you just made and tested it, it still seems non-functional and I used the OTG cable itself to test. It seems to be able to detect the mice models/manufacturers now but still not send any data to the host.

Output:
```
Blinking keyboard LEDs
HID(1,0,KEYBOARD) mounted
 ID: 045e:0752
 Manufa,W���� Microsoft
 Product:      Wired Keyboard 400

HID(1,0,KEYBOARD) registered for reports
HID has 1 reports
HID(2,1,MOUSE) mounted
 ID: 17ef:608d
 Manufacturer: PixArt
 Product:      Lenovo USB Optical Mouse

HID(2,1,MOUSE) registered for reports
HID(2,1) unmounted
HID(1,0) unmounted
HID has 1 reports
HID(1,0,MOUSE) mounted
 ID: 17ef:608d
 Manufacturer: PixArt
 Product:      Lenovo USB Optical Mouse

HID(1,0,MOUSE) registered for reports
HID(1,0) unmounted
HID has 1 reports
HID(1,0,MOUSE) mounted
 ID: 045e:0053
 Manufacturer: Microsoft
 Product:      Microsoft 3-Button Mouse with IntelliEye(TM)

HID(1,0,MOUSE) registered for reports
HID(1,0) unmounted
```

No0ne, 2024-11-14:
The mouse data to the host is only sent if the host enables mouse streaming mode (0xf4) via the PS/2 port.
So you have to see the following first in the debug log, try rebooting your host:
```
host > ms ff
ms > host fa
kb > host f0
kb > host 5a
ms > host aa
ms > host 00
host > ms e8
ms > host fa
host > ms 03
ms > host fa
host > ms f2
ms > host fa
ms > host 00
host > ms f3
ms > host fa
host > ms c8
ms > host fa
host > ms f3
ms > host fa
host > ms 64
ms > host fa
host > ms f3
ms > host fa
host > ms 50
ms > host fa
host > ms f2
ms > host fa
ms > host 03
host > ms ff
ms > host fa
ms > host aa
ms > host 00
host > ms f3
ms > host fa
host > ms c8
ms > host fa
host > ms f3
ms > host fa
host > ms 64
ms > host fa
host > ms f3
ms > host fa
host > ms 50
ms > host fa
host > ms f4
```

Justasic, 2024-11-14:
I've rebooted my host and the mouse is not working, keyboard still functions though. I wonder if maybe I've swapped the pins in the PS/2 port. I have pin 2 (based on the plug pin diagram in the readme) going to GPIO 11 and pin 6 going to GPIO 12. I would assume these are correct. I checked my BIOS for any PS/2-related settings but it didn't seem to have any.

Actually, this may be something else, I tried with a real PS/2 mouse in the PS/2 port and it's not working as well. *sigh* maybe this is some form of user error :sweat_smile: I'll try rebooting again and see if the PS/2 mouse is recognized.

No0ne, 2024-11-15:
A mouse is normally not wired for a dual-port, try a PS/2 Y-splitter if you have one.
Does it work now?

Justasic, 2024-11-15:
Ok after some testing, the port works with a PS/2 mouse but only after I reboot the machine. When I try to plug it in after having a keyboard plugged in or if I try to use a splitter cable, the PS/2 mouse stops working. If I try to plug the pico pi into the port, I get no mouse even after a reboot and only having a mouse plugged in. I understand that PS/2 is not hot-swap, I just find it interesting it doesn't seem to be initializing a mouse correctly even at boot.

For more information: I have an ASUS X670-p wifi motherboard and I've read online that there seems to be some issues with ASUS's support of PS/2 hardware. The rational behind me using PS/2 is because I use QubesOS.

No0ne, 2024-11-15:
Do you see any **host > ms** messages in the debug log?

Justasic, 2024-11-20:
Apologies for the delay, things got busy. I did a few things, first being I plugged the device in and it gave me this output when I plugged it in:
```
bash-5.2# cat /dev/ttyUSB0
�

ps2x2pico-1.3

Setting defaults for keyboard

scancodeset set to 2

kb > host aa

ms > host aa

ms > host 00

Blinking keyboard LEDs

HID has 1 reports

HID(1,0,MOUSE) mounted

 ID: 17ef:608d

 Manufacturer: PixArt

 Product:      Lenovo USB Optical Mouse

HID(1,0,MOUSE) registered for reports
```
Then this output when I rebooted the host and it was in the BIOS:
```
HID(1,0,MOUSE) registered for reports

host > kb f2

KBHOSTCMD_READ_ID_F2

kb > host fa

kb > host ab

kb > host 83

host > kb ed

KBHOSTCMD_SET_LEDS_ED

kb > host fa

host > kb 02

kb > host fa
```
Then after the OS kernel was executed, I got more output:
```
host > kb f2

KBHOSTCMD_READ_ID_F2

kb > host fa

kb > host ab

kb > host 83

host > kb f5

KBHOSTCMD_DISABLE_F5

kb > host fa

host > kb ed

KBHOSTCMD_SET_LEDS_ED

kb > host fa

host > kb 00

kb > host fa

host > kb f3

KBHOSTCMD_SET_TYPEMATIC_PARAMS_F3

kb > host fa

host > kb 00

kb > host fa

host > kb f4

KBHOSTCMD_ENABLE_F4

kb > host fa
```

However, the mouse did not function.
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
No0ne, 2024-12-01:
Can you try a PS/2 splitter an plug in a real keyboard an mouse at the same time on the B550?

No0ne, 2024-12-01:
I suspect your port and @Justasic can switch between mouse an keyboard but can't do both simultaneously, just a theory!

hax0rbana-adam, 2024-12-01:
I've ordered a splitter to test that theory.

I'm skeptical since using a USB keyboad directly and the ps2x2pico for the mouse doesn't work in the BIOS. It really seems like the ps2x2pico can't output PS/2 mouse signals in a way this motherboard is willing to accept.

Either way, the splitter test should sort this out in short order. I will report back in about a week.

No0ne, 2024-12-02:
If two real PS/2 devices are indeed working and you want to debug this further we also need a cheap 8-channel logic analyzer: https://github.com/No0ne/ps2x2pico/issues/52#issuecomment-2365244262

Justasic, 2024-12-02:
Some initial testing, I have ordered 2 separate splitters and using the keyboard and mouse (both of which worked as expected independently) it seems only the keyboard wants to work. I plugged the mouse in first and then the keyboard but only the keyboard functioned. I have not rebooted my system yet (I'll do that later during lunch) to confirm whether or not it's a motherboard issue.

It will take me a bit of time to get the logic analyzer (likely after Christmas) so if someone else can do that testing, it'd be appreciated :sweat_smile:

Justasic, 2024-12-02:
Yeah, it seems I can't use the keyboard and mouse with a splitter. I've tried two different splitters and I know the keyboard and mouse work independently. Not sure what the point is of putting a dual-port on when it only supports single device communication :/

Anyway, thank you for your help! It may be helpful to add some kind of note to the readme that some motherboards may not support both devices at the same time so future folks aren't confused about why their device doesn't work. I'll let you close this issue in case you want to keep it open to track similar issues others are having in this thread.

I'll see if I can do some more research and maybe find another solution but I doubt it. :grin:

No0ne, 2024-12-03:
Thanks for your research. Does the mouse work on either of the two splitter ports? (so they wired all 6 pins) Does the keyboard also work on both splitter ports?

hax0rbana-adam, 2024-12-05:
My splitter arrived and I have test results: my motherboard only supports a PS/2 keyboard XOR a PS/2 mouse.

I'm offended by this and I hold Asus responsible for my feelings of shock and horror. They really couldn't spend the extra few bucks to support both concurrently? Sheesh.

The splitter I have doesn't label the keyboard side and the mouse side, but it seems to matter. I didn't bust out a multimeter to check for continuity, but it seems that not all 6 pins are wired to both sides. That'd make a lot more sense if at least side one was labeled or color coded, but it was cheap so I guess I got what I paid for.

I'm not sure why I couldn't get my mouse to work in the BIOS with the ps2x2pico (while using a USB keyboard), but I'm going to say it was probably testing error. I'm too discouraged to reboot and tinker with it now that I know the horrible truth about my motherboard's limitations.

I agree with @Justasic that this ticket can be closed by adding "some kind of note to the readme that some motherboards may not support both devices at the same time". I'd also suggest mentioning that this doesn't seem to be correlated to price so people don't fall into the mental trap of "oh, I have a really nice motherboard, of course it'll support both at the same time". Maybe mention the Asus ProArt B550-creator as an example?

At any rate, I am glad we got to the bottom of this. It's probably more frustrating to have these unsolved mysteries and open tickets that just hang around forever.

No0ne, 2024-12-05:
Yeah thats bad :( I'll add that to the readme.

Normally a splitter should be wired like this:
| Plug    | Keyboard Socket | Mouse Socket |
|---------|-----------------|--------------|
| 1 Data KB  | 1 Data          | -            |
| 2 Data MS | -               | 1 Data       |
| 3 GND   | 3 GND           | 3 GND        |
| 4 +5V   | 4 +5V           | 4 +5V        |
| 5 Clock KB | 5 Clock         | -            |
| 6 Clock MS | -               | 5 Clock      |

Closed 2024-12-05.

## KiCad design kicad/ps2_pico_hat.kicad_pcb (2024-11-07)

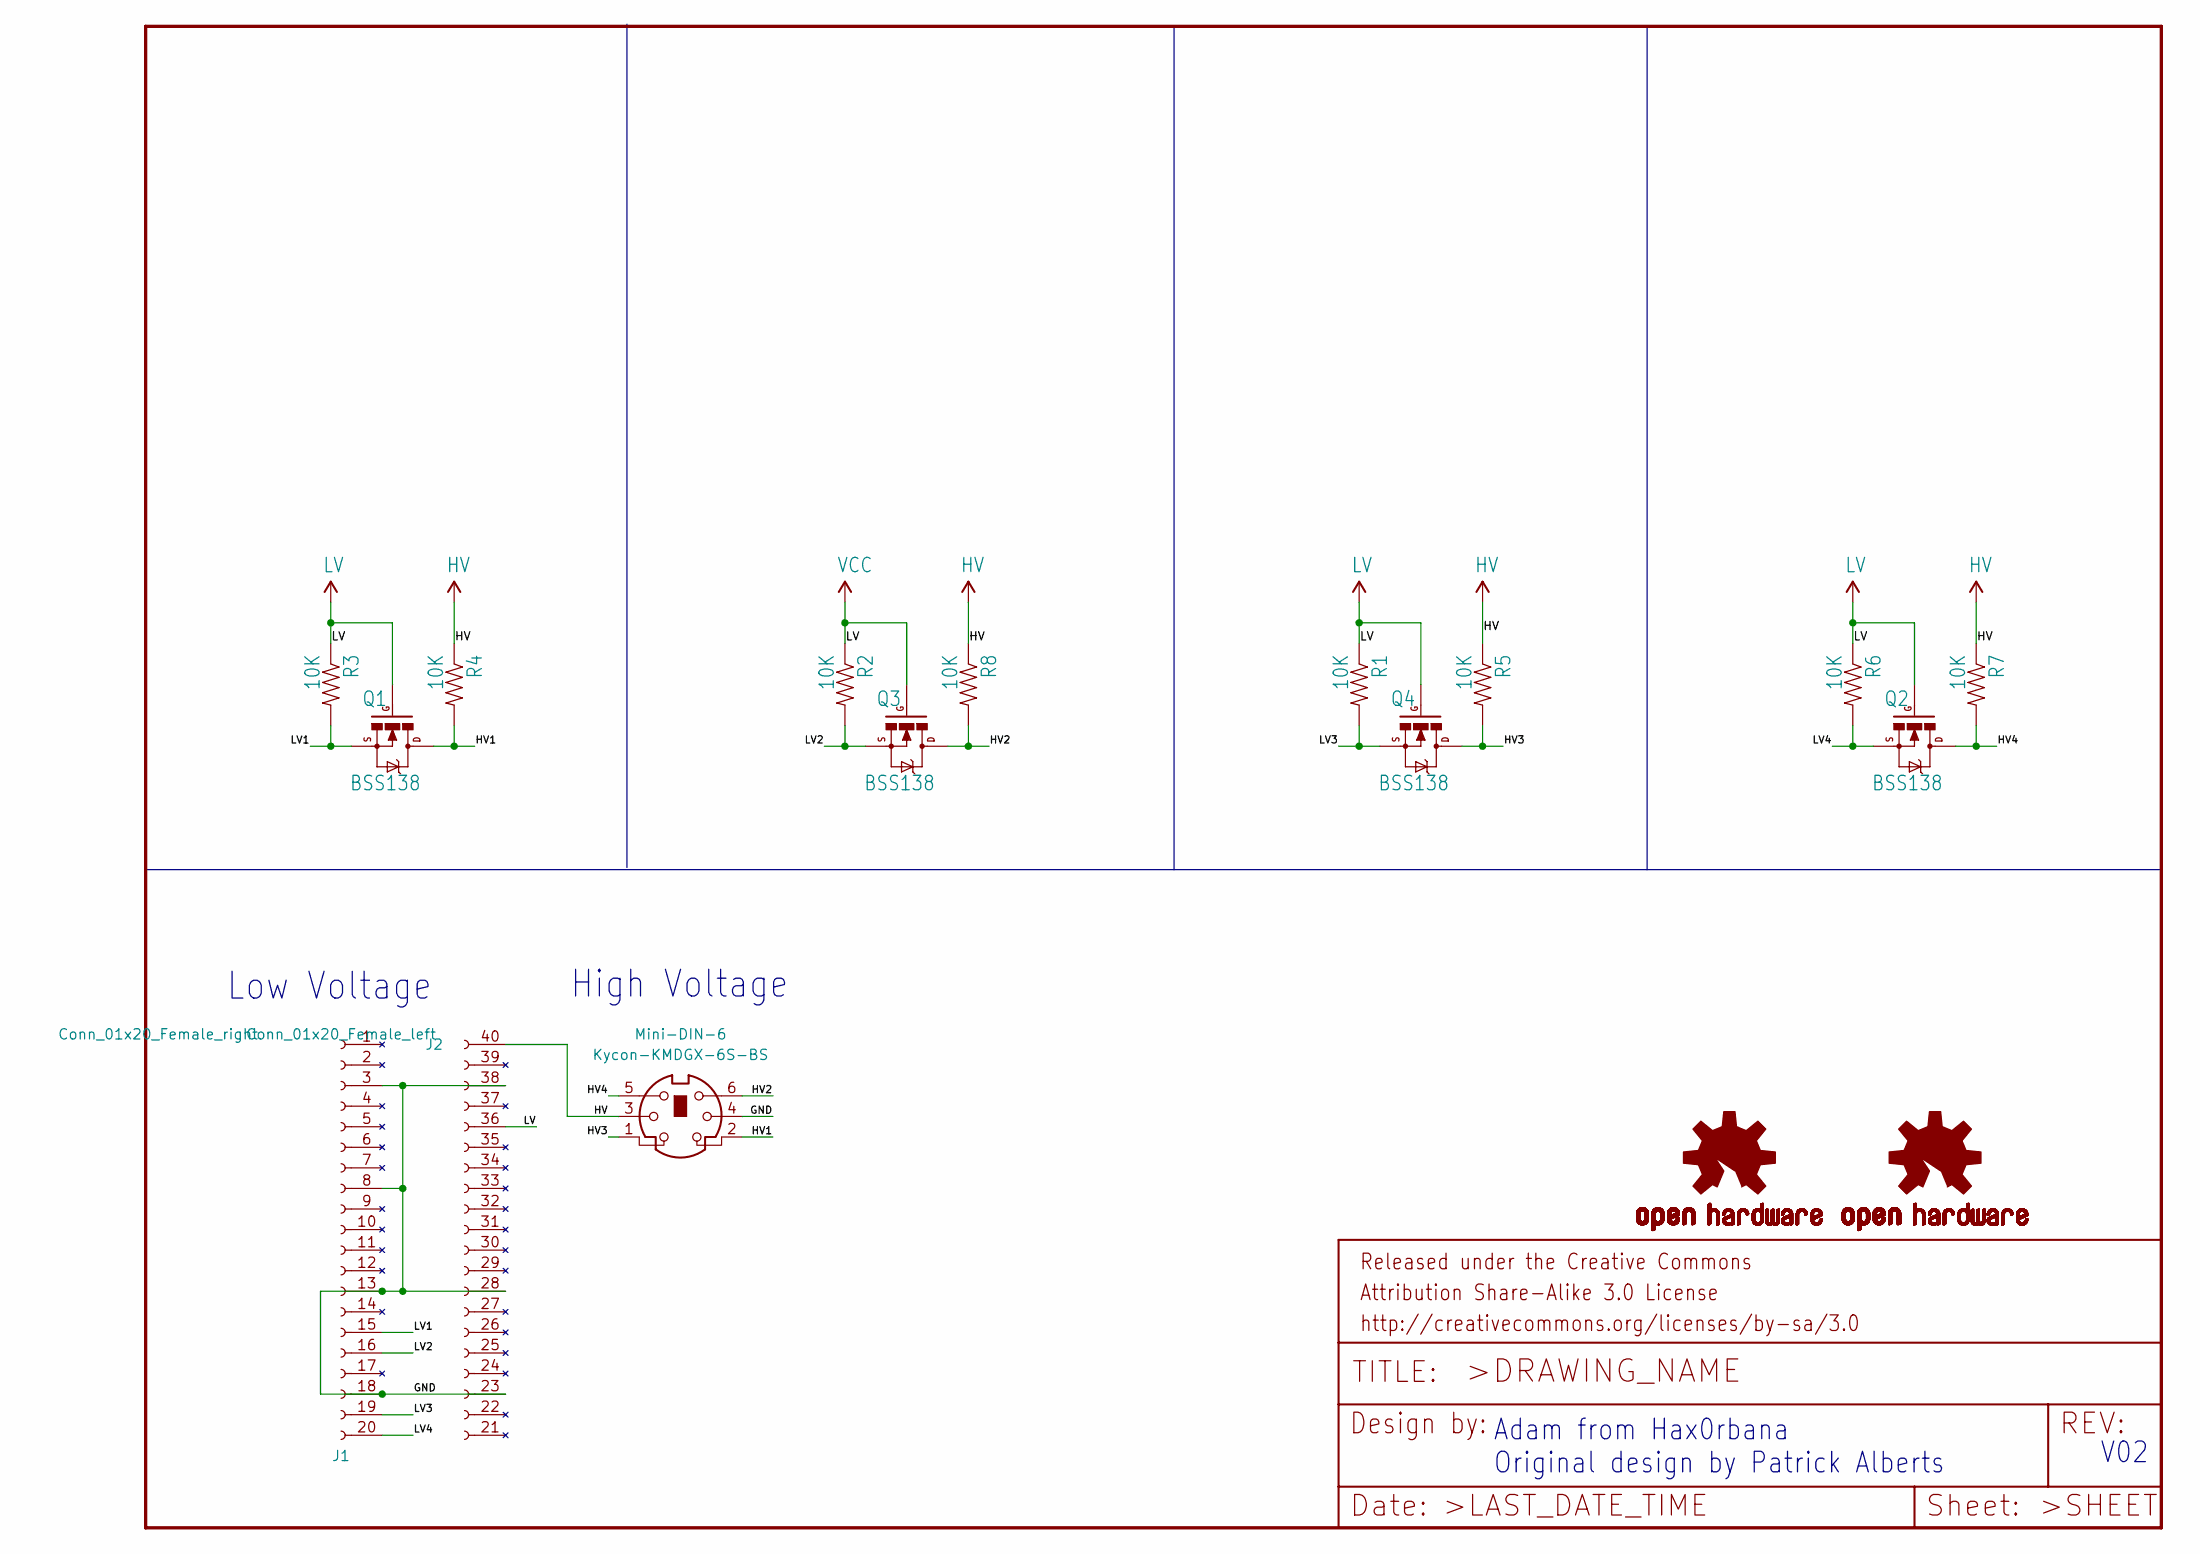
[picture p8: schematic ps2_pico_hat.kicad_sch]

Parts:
J1: Conn_01x20_Female_left; PinSocket_1x20_P2.54mm_Vertical
J2: Conn_01x20_Female_right; PinSocket_1x20_P2.54mm_Vertical
LOGO1, LOGO2: OSHW-LOGOS; OSHW-LOGO-S
Mini-DIN-6: Kycon-KMDGX-6S-BS; KMDGX-6S-BS
Q1, Q2, Q3, Q4: BSS138; SOT23-3
R1, R2, R3, R4, R5, R6, R7, R8: 10K; 0603-RES

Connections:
/GND: J1.3 (GND), J1.8 (GND), J1.13 (GND), J1.18 (GND), J2.23 (GND), J2.28 (GND), J2.38 (GND), Mini-DIN-6.4
/HV1: Mini-DIN-6.2, Q1.3 (D), R4.2
/HV2: Mini-DIN-6.6, Q3.3 (D), R8.2
/HV3: Mini-DIN-6.1, Q4.3 (D), R5.2
/HV4: Mini-DIN-6.5, Q2.3 (D), R7.2
/LV1: J1.15, Q1.2 (S), R3.2
/LV2: J1.16, Q3.2 (S), R2.2
/LV3: J1.19, Q4.2 (S), R1.2
/LV4: J1.20, Q2.2 (S), R6.2
HV: J2.40, Mini-DIN-6.3, R4.1, R5.1, R7.1, R8.1
LV: J2.36 (LV), Q1.1 (G), Q2.1 (G), Q3.1 (G), Q4.1 (G), R1.1, R2.1, R3.1, R6.1

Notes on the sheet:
Low Voltage
V02
Adam from Hax0rbana Original design by Patrick Alberts
High Voltage

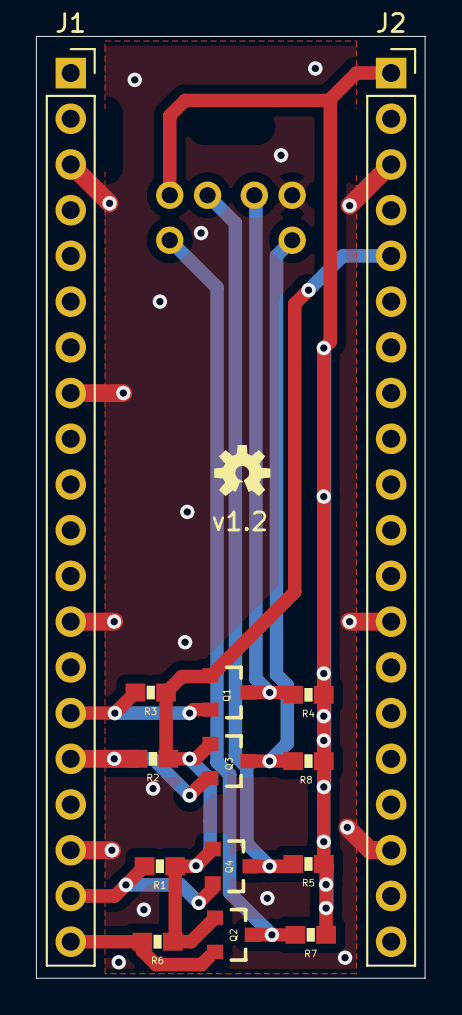
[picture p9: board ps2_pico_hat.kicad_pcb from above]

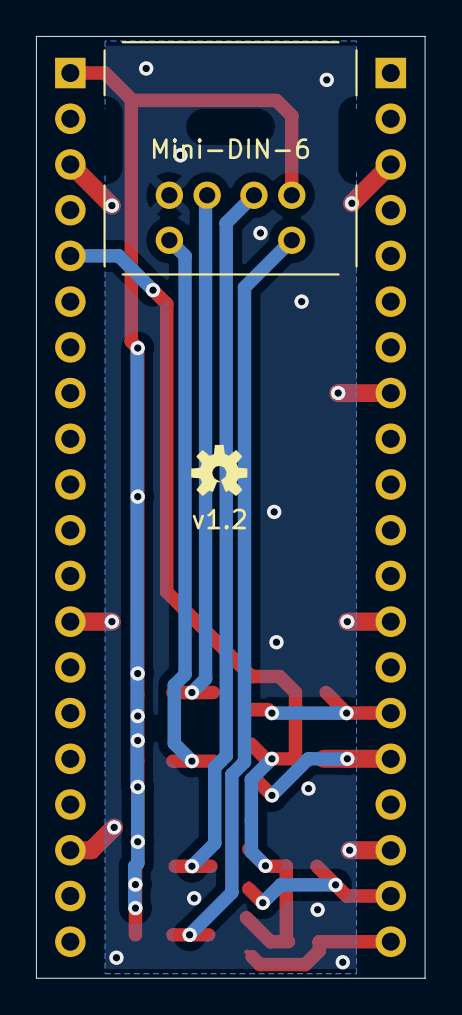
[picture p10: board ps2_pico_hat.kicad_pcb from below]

Board: 2 copper layers, 21.6 x 52.3 mm, 17 parts (2 on the bottom side), 11 nets.

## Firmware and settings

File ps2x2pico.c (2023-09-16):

/*
 * The MIT License (MIT)
 *
 * Copyright (c) 2022 No0ne (https://github.com/No0ne)
 *           (c) 2023 Dustin Hoffman
 *
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
 */

#include "hardware/gpio.h"
#include "bsp/board.h"
#include "tusb.h"
#include "ps2x2pico.h"

u8 kb_addr = 0;
u8 kb_inst = 0;
u8 kb_leds = 0;

void tuh_kb_set_leds(u8 leds) {
  if(kb_addr) {
    kb_leds = leds;
    printf("HID device address = %d, instance = %d, LEDs = %d\n", kb_addr, kb_inst, kb_leds);
    tuh_hid_set_report(kb_addr, kb_inst, 0, HID_REPORT_TYPE_OUTPUT, &kb_leds, sizeof(kb_leds));
  }
}

void tuh_hid_mount_cb(u8 dev_addr, u8 instance, u8 const* desc_report, u16 desc_len) {
  printf("HID device address = %d, instance = %d is mounted\n", dev_addr, instance);

  switch(tuh_hid_interface_protocol(dev_addr, instance)) {
    case HID_ITF_PROTOCOL_KEYBOARD:
      printf("HID Interface Protocol = Keyboard\n");
      
      kb_addr = dev_addr;
      kb_inst = instance;
      kb_reset();
      
      tuh_hid_receive_report(dev_addr, instance);
    break;
    
    case HID_ITF_PROTOCOL_MOUSE:
      printf("HID Interface Protocol = Mouse\n");
      //tuh_hid_set_protocol(dev_addr, instance, HID_PROTOCOL_REPORT);
      tuh_hid_receive_report(dev_addr, instance);
    break;
  }
}

void tuh_hid_umount_cb(u8 dev_addr, u8 instance) {
  printf("HID device address = %d, instance = %d is unmounted\r\n", dev_addr, instance);
  
  if(dev_addr == kb_addr && instance == kb_inst) {
    kb_addr = 0;
    kb_inst = 0;
  }
}

void tuh_hid_report_received_cb(u8 dev_addr, u8 instance, u8 const* report, u16 len) {
  board_led_write(1);
  
  switch(tuh_hid_interface_protocol(dev_addr, instance)) {
    case HID_ITF_PROTOCOL_KEYBOARD:
      kb_usb_receive(report);
      tuh_hid_receive_report(dev_addr, instance);
    break;
    
    case HID_ITF_PROTOCOL_MOUSE:
      ms_usb_receive(report);
      tuh_hid_receive_report(dev_addr, instance);
    break;
  }
  
  board_led_write(0);
}

void main() {
  board_init();
  printf("\n%s-%s\n", PICO_PROGRAM_NAME, PICO_PROGRAM_VERSION_STRING);
  
  gpio_init(LVPWR);
  gpio_set_dir(LVPWR, GPIO_OUT);
  gpio_put(LVPWR, 1);
  
  tusb_init();
  kb_init(KBDAT);
  ms_init(MSDAT);
  
  while(true) {
    tuh_task();
    kb_task();
    ms_task();
  }
}

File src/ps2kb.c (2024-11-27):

/*
 * The MIT License (MIT)
 *
 * Copyright (c) 2024 No0ne (https://github.com/No0ne)
 *           (c) 2023 Dustin Hoffman
 *
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
 */
#include "ps2x2pico.h"

ps2out kb_out;
ps2in kb_in;

#define KBHOSTCMD_RESET_FF 0xff
#define KBHOSTCMD_RESEND_FE 0xfe
#define KBHOSTCMD_SCS3_SET_KEY_MAKE_FD 0xfd
#define KBHOSTCMD_SCS3_SET_KEY_MAKE_BREAK_FC 0xfc
#define KBHOSTCMD_SCS3_SET_KEY_MAKE_TYPEMATIC_FB 0xfb
#define KBHOSTCMD_SCS3_SET_ALL_MAKE_BREAK_TYPEMATIC_FA 0xfa
#define KBHOSTCMD_SCS3_SET_ALL_MAKE_F9 0xf9
#define KBHOSTCMD_SCS3_SET_ALL_MAKE_BREAK_F8 0xf8
#define KBHOSTCMD_SCS3_SET_ALL_MAKE_TYPEMATIC_F7 0xf7
#define KBHOSTCMD_SET_DEFAULT_F6 0xf6
#define KBHOSTCMD_DISABLE_F5 0xf5
#define KBHOSTCMD_ENABLE_F4 0xf4
#define KBHOSTCMD_SET_TYPEMATIC_PARAMS_F3 0xf3
#define KBHOSTCMD_READ_ID_F2 0xf2
#define KBHOSTCMD_SET_SCAN_CODE_SET_F0 0xf0
#define KBHOSTCMD_ECHO_EE 0xee
#define KBHOSTCMD_SET_LEDS_ED 0xed

#define KB_MSG_SELFTEST_PASSED_AA 0xaa
#define KB_MSG_ID1_AB 0xab
#define KB_MSG_ID2_83 0x83
#define KB_MSG_ECHO_EE 0xee
#define KB_MSG_ACK_FA 0xfa
#define KB_MSG_RESEND_FE 0xfe

typedef enum {
  KBH_STATE_IDLE,
  KBH_STATE_SET_LEDS_ED,
  KBH_STATE_SET_SCAN_CODE_SET_F0,
  KBH_STATE_SET_TYPEMATIC_PARAMS_F3,
  KBH_STATE_SET_KEY_MAKE_FD,
  KBH_STATE_SET_KEY_MAKE_BREAK_FC,
  KBH_STATE_SET_KEY_MAKE_TYPEMATIC_FB
} kbhost_state_enum_t;

kbhost_state_enum_t kbhost_state = KBH_STATE_IDLE;

typedef enum {
  SCS3_MODE_MAKE,
  SCS3_MODE_MAKE_BREAK,
  SCS3_MODE_MAKE_TYPEMATIC,
  SCS3_MODE_MAKE_BREAK_TYPEMATIC,
} scs3_mode_enum_t;

scs3_mode_enum_t scs3_mode = SCS3_MODE_MAKE_BREAK_TYPEMATIC;

#define SCAN_CODE_SET_1 1
#define SCAN_CODE_SET_2 2
#define SCAN_CODE_SET_3 3

u8 scancodeset = SCAN_CODE_SET_2;

#define HOST_CMD_MIN 0xe0
#define KEYMODEMASK_BREAK 0b00000001
#define KEYMODEMASK_TYPEMATIC 0b00000010

u8 scs3keymodemap[HOST_CMD_MIN];

u8 const led2ps2[] = { 0, 4, 1, 5, 2, 6, 3, 7 };

u32 const repeats[] = {
  33333, 37453, 41667, 45872, 48309, 54054, 58480, 62500,
  66667, 75188, 83333, 91743, 100000, 108696, 116279, 125000,
  133333, 149254, 166667, 181818, 200000, 217391, 232558, 250000,
  270270, 303030, 333333, 370370, 400000, 434783, 476190, 500000
};
u16 const delays[] = { 250, 500, 750, 1000 };

bool kb_enabled = true;
bool blinking = false;
u8 key2repeat = 0;
u8 last_byte_sent = 0;
u32 repeat_us;
u16 delay_ms;
alarm_id_t repeater;

void kb_send(u8 byte) {
  if(byte != KB_MSG_RESEND_FE) last_byte_sent = byte;
  printf("kb > host %02x\n", byte);
  queue_try_add(&kb_out.qbytes, &byte);
}

void kb_resend_last() {
  printf("r: k>h %x\n", last_byte_sent);
  queue_try_add(&kb_out.qbytes, &last_byte_sent);
}

void kb_maybe_send_prefix(u8 key) {
  u8 const *l = IS_MOD_KEY(key) ? ext_code_modifier_keys_1_2 : ext_code_keys_1_2;
  for(int i = 0; l[i]; i++) {
    if(key == l[i]) {
      kb_send(KB_EXT_PFX_E0);
      break;
    }
  }
}

// sends out scan codes from a null byte terminated list
void kb_send_sc_list(const u8 *list) {
  key2repeat = 0;
  for(int i = 0; list[i]; i++) {
    kb_send(list[i]);
  }
}

void kb_set_leds(u8 byte) {
  if(byte > 7) byte = 0;
  tuh_kb_set_leds(led2ps2[byte]);
  #ifdef KBIN
    ps2in_set(&kb_in, 0xed, byte);
  #endif
}

s64 blink_callback() {
  if(blinking) {
    printf("Blinking keyboard LEDs\n");
    kb_set_leds(KEYBOARD_LED_NUMLOCK | KEYBOARD_LED_CAPSLOCK | KEYBOARD_LED_SCROLLLOCK);
    blinking = false;
    return 500000;
  }
  kb_set_leds(0);
  return 0;
}

void set_scancodeset(u8 scs) {
  scancodeset = scs;
  printf("scancodeset set to %u\n", scancodeset);
}

void kb_set_defaults() {
  printf("Setting defaults for keyboard\n");
  kbhost_state = KBH_STATE_IDLE;
  scs3_mode = SCS3_MODE_MAKE_BREAK_TYPEMATIC;
  set_scancodeset(2);
  kb_enabled = true;
  repeat_us = 91743;
  delay_ms = 500;
  blinking = true;
  add_alarm_in_ms(100, blink_callback, NULL, false);
  #ifdef KBIN
    ps2in_reset(&kb_in);
  #endif
}

s64 repeat_cb() {
  if(key2repeat) {
    switch(scancodeset) {
      case SCAN_CODE_SET_1:
        kb_maybe_send_prefix(key2repeat);
        IS_MOD_KEY(key2repeat) ? kb_send(mod2ps2_1[key2repeat - HID_KEY_CONTROL_LEFT]) : kb_send(hid2ps2_1[key2repeat]);
      break;
      case SCAN_CODE_SET_2:
        kb_maybe_send_prefix(key2repeat);
        IS_MOD_KEY(key2repeat) ? kb_send(mod2ps2_2[key2repeat - HID_KEY_CONTROL_LEFT]) : kb_send(hid2ps2_2[key2repeat]);
      break;
      case SCAN_CODE_SET_3:
        IS_MOD_KEY(key2repeat) ? kb_send(mod2ps2_3[key2repeat - HID_KEY_CONTROL_LEFT]) : kb_send(hid2ps2_3[key2repeat]);
      break;
      default:
        repeater = 0;
      return 0;
    }
    return repeat_us;
  }
  repeater = 0;
  return 0;
}

#define LOG_UNMAPPED_KEY printf("WARNING: Unmapped HID key 0x%x in set %d, ignoring it!\n",key,scancodeset);

void kb_send_key_scs1(u8 key, bool is_key_pressed, bool is_ctrl) {

  // PrintScreen and Pause have special sequences that must be sent.
  // Pause doesn't have a break code.
  if(key == HID_KEY_PAUSE || key == HID_KEY_PRINT_SCREEN) {
    if(is_key_pressed  && key == HID_KEY_PRINT_SCREEN)      kb_send_sc_list(prt_scn_make_1);
    if(!is_key_pressed && key == HID_KEY_PRINT_SCREEN)      kb_send_sc_list(prt_scn_break_1);
    if(is_key_pressed  && key == HID_KEY_PAUSE && is_ctrl)  kb_send_sc_list(break_make_1);
    if(is_key_pressed  && key == HID_KEY_PAUSE && !is_ctrl) kb_send_sc_list(pause_make_1);
    return;
  }

  u8 scan_code = IS_MOD_KEY(key) ? mod2ps2_1[key - HID_KEY_CONTROL_LEFT] : hid2ps2_1[key];

  if(!scan_code) {
    LOG_UNMAPPED_KEY
    return;
  }

  // Some keys require a prefix before the actual code
  kb_maybe_send_prefix(key);

  if(is_key_pressed) {
    // Take care of typematic repeat
    key2repeat = key;
    if(repeater) cancel_alarm(repeater);
    repeater = add_alarm_in_ms(delay_ms, repeat_cb, NULL, false);

    kb_send(scan_code);
  } else {
    // Cancel repeat
    if(key == key2repeat) key2repeat = 0;

    kb_send(scan_code | 0x80);
  }
}
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

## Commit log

2022-09-11 alpha-0.1 - mouse wheel not working + lots of cleanup needed
    [ps2x2pico.c]
2022-09-11 alpha-0.2 - mouse wheel working, cleanup still needed
2022-11-05 fix timing issue on NuXTv2
    [ps2x2pico.c]
2023-01-28 Fixed documentation and removed bad comments.
    [ps2x2pico.c]
2023-02-04 fix scroll wheel up represenation
    There are only 4 bit available for scroll wheel movement, not 8 bit.
    Use (0x10 - z) to get the proper 4 bit complement.
    [ps2x2pico.c]
2023-02-05 add support for mouse button 4 & 5
2023-04-28 update keyboard prev_rpt atomically
    Modifying previous HID report during parsing of current HID report may
    lead to spurious PS/2 key presses: some HID devices report 2nd key in
    a combo by shifting the report to the right and saving that key in the
    1st report slot, essentially overwriting the 1st key in prev_rpt. The
    1st key in the 2nd slot will be reported once more, as it is missing
    from prev_rpt.
    [ps2x2pico.c]
2024-03-05 fix mouse sample rate
    [ps2ms.c]
2024-03-06 clamp xyz and send rest in next package
2024-03-06 fix mouse movement overflow
    [ps2ms.c]
2024-03-25 Add compile-time configuration of mouse sample rate behavior
2024-03-28 200hz mouse optimization
2024-04-19 Note that VBUS == Vin in README diagram
    Some Pi Pico boards silkscreen `Vin` on the `VBUS` pin and mentioning it by that name would make it simpler for novices to assemble their own ps2x2picos.
    ...as well as improve the confidence of people like me who had to read a page like [this](https://randomnerdtutorials.com/raspberry-pi-pico-w-pinout-gpios/) that says "The VBUS (USB Power Input) is t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
2024-04-19 Revert addition of Vin due to contradictory uses
    It turns out that some people use Vin to mean "voltage input" (i.e. VBUS) and some people use it to mean "voltage internal" (i.e. VSYS), so just go back to the old diagram.
2024-05-17 Scan code set 3 fully implemented and tested, scan code set 1 added (untested), minor USB fixes (#39)
    * First working version for scan code set 3 and SGI O2
    * Added archive.org links for scan code sets etc.
    * scan code set 1 implemented, refactoring
    * Fixed type ssc->scs
    * resend mechanism corrected
    * Fixed USB problems with Dell kb, refactoring, europe keys in set3
    * completed scs3 functions, completed scs for europe1/2 keys
    * fixed bug of missing e0s for modifiers in scs1 and scs2
    [ps2kb.c, ps2x2pico.c]
2024-05-19 allow keyrepat thru host reset, fix ps2phy sent bytes underflow
    [ps2kb.c, ps2x2pico.c]
2024-05-19 fix left ctrl typematic
    [ps2kb.c]
2024-05-19 revert 0xaa reset response
    [ps2kb.c]
2024-06-08 24 ps2 input (#45)
    * ps/2 input testing
    * keyboard passthru support
    * input testing
    * keyboard+mouse input
    * fix mouse sample rate
    * clamp xyz and send rest in next package
    * fix mouse movement overflow
    * ready to merge
    [ps2kb.c, ps2ms.c, ps2x2pico.c]
2024-07-27 fix PiKVM compile warnings
    [ps2kb.c, ps2ms.c, ps2x2pico.c]
2024-09-30 docs: improved documentation for compiling and disambiguated comments about GPIO numbers vs pin numbers
2024-10-13 cad: added pico hat to implement the hardware for this project
    [ps2_pico_hat-B_Cu.gbr, ps2_pico_hat-B_Mask.gbr, ps2_pico_hat-B_Paste.gbr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]
2024-10-15 feat: added CAD model for a 3D printed case
    [case.FCStd]
2024-10-15 doc: added photos of pico hat and cases
2024-10-19 docs: added version number to PCB
    [ps2_pico_hat.kicad_pcb]
2024-11-07 Improved documentation for the hat
    - Changed label on J3 to J2
    - Added missing links to components
    - Regenerated the iBOM with links to buy components
    - Removed backup files committed in error
    [ps2_pico_hat.kicad_pcb, ps2_pico_hat.kicad_sch]
2024-11-14 pre-1.3: mouse now runs in report mode with Pico-SDK 1.5.1
2024-11-20 report mode for every device
2024-11-28 USB replugging still doesn't work with PicoSDK-2.1.0
    [ps2ms.c]
2026-02-12 feat: Add level shift OpenSCAD case (#94)
    Thanks for that!
    [bottom.scad, cable_holes.scad, chamfered_section.scad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]

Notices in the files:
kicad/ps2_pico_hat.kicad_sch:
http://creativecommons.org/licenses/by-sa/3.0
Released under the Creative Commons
